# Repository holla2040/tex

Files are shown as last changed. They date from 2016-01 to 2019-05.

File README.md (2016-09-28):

# tex
    RaspberryPi super controller board for multiple uses: for example museum static airplanes, solar tracker and off-grid water turbine automation.  

### features
<pre>
Overview
    Sensors
        8 analog inputs multiplexed to 12bit ADC at 3KSPS
            Used for temperature, light, voltage, current,
            pressure, flow, AC line sync, etc
        1 power supply current sense ADC

    User Interface
        2 board-mounted user input switches
        3 board-mounted indicator LEDS: R,G,B
        1 128x64 White OLED Display Module
        All connectors are plug-type for easy board replacement
        
    Control
        16 PWM-driven voltage outputs at 7A max with board indicator
        4 dry-contact 10A relays with COM/NC/NO connector
        2 120VAC/8A solid-state relays
        2 DC Motor H-bridge drivers with current sense
            * uses 4 of 16 outputs from above
            Motor direction indicator
        2 opto-coupled inputs for DC motor motion encoders
        2 stepper motor driver signalling outputs, EN/DIR/PULSE
        10 uncommitted digital +5 I/O signals
        
    Peripherals
        Board tempurature sensor
        Battery backed real-time clock 

    Power Supply
        12-26VDC operation, PWM outputs switch this voltage
        +5V DC/DC converter
        Reverse battery protection
        ATF automobile fuse
        
    Communication
        WiFi/Bluetooth 4.0/Ethernet supplied on Raspberry Pi 3
        RS-485 2/4 wire with termination resistor
        External I2C/Power/Ground connector
</pre>
<hr>
<pre>
Detailed
    DC motor 1 h-bridge            discrete fets
    DC motor 1 encoder             cpu interrupt opto-coupled
    DC motor 1 current detect      gain
    DC motor 2 h bridge            discrete fets
    DC motor 2 encoder             cpu interrupt opto-coupled
    DC motor 2 current detect      gain
    AC SSR 1                       i/o slow, unfused
    AC SSR 2                       i/o slow, unfused
    Temperature sensor 1           multiplexed, 10k pullup
    Temperature sensor 2           multiplexed, 10k pullup
    Temperature sensor 3           multiplexed, 10k pullup
    Temperature sensor 4           multiplexed, 10k pullup
    Pyranometer                    analog input with gain
    LED Driver 0                   pwm
    LED Driver 1                   pwm
    LED Driver 2                   pwm
    LED Driver 3                   pwm
    LED Driver 4                   pwm
    LED Driver 5                   pwm
    LED Driver 6                   pwm
    LED Driver 7                   pwm
    LED Driver 8                   pwm
    LED Driver 9                   pwm
    LED Driver 10                  pwm
    LED Driver 11                  pwm
    LED Driver 12                  pwm, push-pull coupled with 13
    LED Driver 13                  pwm, push-pull coupled with 12
    LED Driver 14                  pwm, push-pull coupled with 15
    LED Driver 15                  pwm, push-pull coupled with 14
    Relay 0                        i/o slow, NO/NC contacts
    Relay 1                        i/o slow, NO/NC contacts
    Relay 2                        i/o slow, NO/NC contacts
    Relay 3                        i/o slow, NO/NC contacts
    E-stop input                   cpu interrupt
    Water Pressure                 0-5VDC input
    Water Flow Rate                0-5VDC input with scaler
    External AC voltage detect     0-5VDC input with scaler, half-wave
    External AC current sensor     0-5VDC input with scaler, half-wave
    External AC frequency sensor   use adc from AC V or I sensor
    External 5VDC I/O 0            I/O slow, change interrupt exists
    External 5VDC I/O 1            I/O slow, change interrupt exists
    External 5VDC I/O 2            I/O slow, change interrupt exists
    External 5VDC I/O 3            I/O slow, change interrupt exists
    External 5VDC I/O 4            I/O slow, change interrupt exists
    External 5VDC I/O 5            I/O slow, change interrupt exists
    External 5VDC I/O 6            I/O slow, change interrupt exists
    External 5VDC I/O 7            I/O slow, change interrupt exists
    External 5VDC I/O 8            I/O slow, change interrupt exists
    External 5VDC I/O 9            I/O slow, change interrupt exists
    Stepper control A              enable, direction, step outputs
    Stepper control B              enable, direction, step outputs
    Power supply current monitor   high-side current monitor
    Display                        OLED 0.96 mount intended
    Reverse Battery Protection     FET biased forward bias protection 
</pre>

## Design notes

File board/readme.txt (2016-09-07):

This information, board files, assembly instructions and bill of
materials are company confidental.
Not for distribution.

board
    tex

version
    v0.1

date
    160906

svn revision
    n/a

fudicials at
    6mm,6mm
    194mm,94mm

2 layer description
    2 layer board
        crc component cream
        plc component side silkscreen
        stc component side solder stop mask
        cmp component side copper
        sol solder side copper
        sts solder side solder stop mask
        pls solder side silkscreen
        crs solder cream

        drd drill data
        dri drill info
        gpi gerber info

2 layer stack up sequence
    top     x.cmp
    bottom  x.sol

contact info
    Craig Hollabaugh
    970 690 4911
    craig@hollabaugh.com

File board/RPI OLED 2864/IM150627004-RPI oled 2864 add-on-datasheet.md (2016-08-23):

# Raspberry PI OLED 2864 Add-on V2.0 #

## Introduction ##

There are seldom OLED add-ons customized for Raspberry Pi in the open source hardware market. In a lot of projects, we only need to display little information such as the state of system or IP. What’s more, when we have a high requirement for its portability, it’s unsuitable to connect a big screen to Raspberry Pi via HDMI interface. Thus, a tiny OLED add-on can satisfy this demand.

OLED add-on with built-in 0.96" 128*64 OLED and SSD1306 control chip is customized for Raspberry Pi. Every single pixel in OLED can be lighted up or off by this SSD1306 control chip.

We not only offer an easily-plugged add-on for Raspberry Pi, but also provide an SDK that help you transplant Arduino’s driver into Raspberry Pi. After installing the SDK, you can drive this add-on as easily as you do on Arduino.

## Feature ##

- Customized for Raspberry Pi, plug and play without wiring

- 0.96" OLED with 128*64 pixels

- Stackable

- Coming with 2.54 interface for Electronic bricks

## Specification ##

<table>
<tr>
  <th>PCB size</th>
  <td>65mm X 43mm X 1.6mm</td>
</tr>
<tr>
  <th>Operation Level</th>
  <td>Digital 3.3V DC</td>
</tr>
</table>

## Hardware ##

请看IM150627004-RPI oled 2864 add-on-dimension.pdf

## Pinmap ##

<table>
<tr>
  <th>Raspberry PI Pin N.O.</th>
  <th>Pin name</th>
  <th>Description</th>
</tr>
<tr>
  <td>1</td>
  <td>3.3V</td>
  <td></td>
</tr>
<tr>
  <td>2</td>
  <td>5V</td>
  <td></td>
</tr>
<tr>
  <td>3</td>
  <td>GPIO02</td>
  <td>OLED_SDA</td>
</tr>
<tr>
  <td>4</td>
  <td>5V</td>
  <td></td>
</tr>
<tr>
  <td>5</td>
  <td>GPIO03</td>
  <td>OLED_SCL</td>
</tr>
<tr>
  <td>6</td>
  <td>GND</td>
  <td></td>
</tr>
<tr>
  <td>7</td>
  <td>GPIO04</td>
  <td>OLED_RST</td>
</tr>
<tr>
  <td>8</td>
  <td>GPIO14</td>
  <td>TXD</td>
</tr>
<tr>
  <td>9</td>
  <td>GND</td>
  <td></td>
</tr>
<tr>
  <td>10</td>
  <td>GPIO15</td>
  <td>RXD</td>
</tr>
<tr>
  <td>11</td>
  <td>GPIO17</td>
  <td></td>
</tr>
<tr>
  <td>12</td>
  <td>GPIO18</td>
  <td></td>
</tr>
<tr>
  <td>13</td>
  <td>GPIO27</td>
  <td></td>
</tr>
<tr>
  <td>14</td>
  <td>GND</td>
  <td></td>
</tr>
<tr>
  <td>15</td>
  <td>GPIO22</td>
  <td></td>
</tr>
<tr>
  <td>16</td>
  <td>GPIO23</td>
  <td></td>
</tr>
<tr>
  <td>17</td>
  <td>3.3V</td>
  <td></td>
</tr>
<tr>
  <td>18</td>
  <td>GPIO24</td>
  <td></td>
</tr>
<tr>
  <td>19</td>
  <td>GPIO10</td>
  <td>SPI_MOSI</td>
</tr>
<tr>
  <td>20</td>
  <td>GND</td>
  <td></td>
</tr>
<tr>
  <td>21</td>
  <td>GPIO09</td>
  <td>SPI_MISO</td>
</tr>
<tr>
  <td>22</td>
  <td>GPIO25</td>
  <td></td>
</tr>
<tr>
  <td>23</td>
  <td>GPIO11</td>
  <td>SPI_SCK</td>
</tr>
<tr>
  <td>24</td>
  <td>GPIO08</td>
  <td>SPI_CE0</td>
</tr>
<tr>
  <td>25</td>
  <td>GND</td>
  <td></td>
</tr>
<tr>
  <td>26</td>
  <td>GPIO07</td>
  <td>SPI_CE1</td>
</tr>
<tr>
  <td>27</td>
  <td>ID_SD</td>
  <td></td>
</tr>
<tr>
  <td>28</td>
  <td>ID_SC</td>
  <td></td>
</tr>
<tr>
  <td>29</td>
  <td>GPIO05</td>
  <td></td>
</tr>
<tr>
  <td>30</td>
  <td>GND</td>
  <td></td>
</tr>
<tr>
  <td>31</td>
  <td>GPIO06</td>
  <td></td>
</tr>
<tr>
  <td>32</td>
  <td>GPIO12</td>
  <td></td>
</tr>
<tr>
  <td>33</td>
  <td>GPIO13</td>
  <td></td>
</tr>
<tr>
  <td>34</td>
  <td>GND</td>
  <td></td>
</tr>
<tr>
  <td>35</td>
  <td>GPIO19</td>
  <td></td>
</tr>
<tr>
  <td>36</td>
  <td>GPIO16</td>
  <td></td>
</tr>
<tr>
  <td>37</td>
  <td>GPIO26</td>
  <td></td>
</tr>
<tr>
  <td>38</td>
  <td>GPIO20</td>
  <td></td>
</tr>
<tr>
  <td>39</td>
  <td>GND</td>
  <td></td>
</tr>
<tr>
  <td>40</td>
  <td>GPIO21</td>
  <td></td>
</tr>
</table>

## Download ##

schematic: 请看IM150627004-RPI oled 2864 add-on-schematic.pdf

## Useful Link ##

https://github.com/itead/SDK

https://github.com/itead/SDK/tree/master/libraries/itead_SSD1306

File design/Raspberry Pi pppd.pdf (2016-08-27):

let's make | Explore (/tag/typeid/) (http://www.instructables.com/tag/type-id/) | Publish (/about/create.jsp) (http://www.instructables.com/about/create.jsp)
| Classes NEW! (/classes/) (http://www.instructables.com/classes/)
Featured: (http://www.instructables.com/) | (/tag/typeid/categorycraft/channelleather/) (http://www.instructables.com/tag/type-id/category-craft/channel-leather/) Leather (/tag/typeid/categorycraft/channelleather/) (http://www.instructables.com/tag/type-id/category-craft/channel-leather/)
(/tag/typeid/categoryoutside/channelcamping/) (http://www.instructables.com/tag/type-id/category-outside/channel-camping/) Camping (/tag/typeid/categoryoutside/channelcamping/) (http://www.instructables.com/tag/type-id/category-outside/channel-camping/) | (/id/intel/) (http://www.instructables.com/id/intel/) Intel IoT (/id/intel/) (http://www.instructables.com/id/intel/)

(/id/Fusion/) (http://www.instructables.com/id/Fusion/) Fusion 360 (/id/Fusion/) (http://www.instructables.com/id/Fusion/)

In this tutorial I will show you how to connect your Raspberry Pi to the Internet just by using its serial line (http://elinux.org/RPi_Serial_Connection) which is accessible on GPIO (http://pi.gadgetoid.com/pinout/uart). This can be very helpful if there is no other means of connection available like ethernet or wifi dongle. The UART serial port is not directly suitable for TCP/IP traffic so we are going to use a PPP protocol that will encapsulate the serial link and give us an IP interface. Please note that the UART is designed to work in kilobits speed range (115.2kbit by default), that's sufficient for ssh and small files transfers, but it will take ages to transfer large files.

The operating principle is very simple, but it may be tricky to setup things properly, especially if your communication is limited to UART only. What you'll need:
Raspberry PI (any model) with Raspbian
USB <> UART convertor + cable with 3.3v logic levels
A linux computer that will act as a second serial link endpoint and a network gateway
Optionally a monitor / keyboard / ethernet / wifi that you can plug to your Raspberry
This method is particularly suitable for the model A as it lacks an ethernet port, but it will work with any Raspberry model. I have the model B rev1.0 :) The convertor can be of any type, I'm using a cheap convertor with a CP2102 chip. As a second endpoint, I'm using my Ubuntu laptop. You don't need anything

(/file/F5BWXWHI4C2R3YB/)

About This Instructable

8 22,992 views

- 32 favorites

Posted:
Dec 31, 2014
License:

(/member/ludeks/)

lude (http://www.instructables.com/member/ludeks/)ks
(/me (http://www.instructables.com/member/ludeks/)mber/ludeks/)

Follow (http://www.instructables.com/member/ludeks/) 1

More by ludeks:

(/id/Connectthe-

Raspberry-Pitonetworkusing-UART/) (http://www.instructables.com/id/Connect-the-Raspberry-Pi-to-network-using-UART/)

raspberry pi (/howto/raspberry%20pi/) (http://www.instructables.com/howto/raspberry%20pi/)

uart (/howto/uart/) (http://www.instructables.com/howto/uart/) serial (/howto/serial/) (http://www.instructables.com/howto/serial/)

ppp (/howto/ppp/) (http://www.instructables.com/howto/ppp/)

Tags:

Add instructable to:

; Group

Related

JT (http://www.instructables.com/id/JTAGulating-the-Raspberry-Pi-2/)AGulating the Raspberry
Pi (http://www.instructables.com/id/JTAGulating-the-Raspberry-Pi-2/) 2 (/id/JTAGulatingthe-Ra (http://www.instructables.com/id/JTAGulating-the-Raspberry-Pi-2/)spberry-Pi-2/)
by (http://www.instructables.com/id/JTAGulating-the-Raspberry-Pi-2/) Tymkrs (/member/Tymkrs/) (http://www.instructables.com/member/Tymkrs/)

RA (http://www.instructables.com/id/RASPBERRY-PI-3-and-RASPBIAN-JESSIE-GSM-3G-SERIAL-H/)SPBERRY PI 3 (and
RA (http://www.instructables.com/id/RASPBERRY-PI-3-and-RASPBIAN-JESSIE-GSM-3G-SERIAL-H/)SPBIAN JESSIE) GSM 3G
SE (http://www.instructables.com/id/RASPBERRY-PI-3-and-RASPBIAN-JESSIE-GSM-3G-SERIAL-H/)RIAL HOW TO
(/id (http://www.instructables.com/id/RASPBERRY-PI-3-and-RASPBIAN-JESSIE-GSM-3G-SERIAL-H/)/RASPBERRY-PI-3-and- (http://www.instructables.com/id/RASPBERRY-PI-3-and-RASPBIAN-JESSIE-GSM-3G-SERIAL-H/)RASPBIAN-JESSIE-GSM-3G-
Hello world to Raspberry Pi through Seeeduino (Uart
port) (/id/Helloworldto-Raspberry-Pithrough- (http://www.instructables.com/id/Hello-world-to-Raspberry-Pi-through-Seeeduino-Uart/)Seeeduino-Uart/)
RFID Based Attendance
System Using Raspberry Pi
(/id/RFID-Based-Attendance (http://www.instructables.com/id/RFID-Based-Attendance-System-Using-Raspberry-Pi/)

(/) (http://www.instructables.com/)

Download

- Collection | I Made it! | Favorite

Connec (http://www.instructables.com/id/Fusion/)t the Raspberry (http://www.instructables.com/id/Fusion/) Pi to network using UART by ludeks (/member/ludeks/) (http://www.instructables.com/member/ludeks/)

7 Steps | .
- | Share |

h (/id/Connectthe-Raspberry-Pitonetworkusing-UART/) (http://www.instructables.com/id/Connect-the-Raspberry-Pi-to-network-using-UART/) sh (http://www.instructables.com/)are what you make (http://www.instructables.com/tag/type-id/category-craft/channel-leather/)

You (/you/) (http://www.instructables.com/you/)

else to plug in to your Raspberry if you setup things correctly, but having a monitor + keyboard and ethernet connection will make the setup easier and can greatly help in case something doesn't work as expected. I needed to connect my Raspberry to the network and I had only a monitor, so it was a lot of trial & error for me to get it working.

### Step 1: Identify USB UART convertor RX / TX lines

You'll need to be sure which pins on the converter are the RX / TX serial lines. Don't rely on markings on the convertor PCB as they may not be correct! You can skip this step if you know which lines are TX and RX.

If you are not sure which line is TX, you can attach a resistor and LED in series to the suspected pin, the LED should blink when you write something to the UART.

Assuming the /dev/ttyUSB0 is the convertor:

# This will make a LED attached to the TX blink once stty -F /dev/ttyUSB0 9600 raw

dd if=/dev/zero of=/dev/ttyUSB0 bs=1000 count=1

Once you have identified the TX pin, you can connect it to the suspected RX pin on the converter to make an echo loop. You should be able to receive what you write to it.

screen /dev/ttyUSB0 115200

When you type characters to the screen session, the screen should echo them when TX-RX are connected.

### Step 2: Wire your computer to the Raspberry Pi

Raspberry Pi Dumb Terminal (/id/Raspberry-Pi-Dumb-Terminal/) (http://www.instructables.com/id/Raspberry-Pi-Dumb-Terminal/)
by Tymkrs (/member/Tymkrs/) (http://www.instructables.com/member/Tymkrs/)

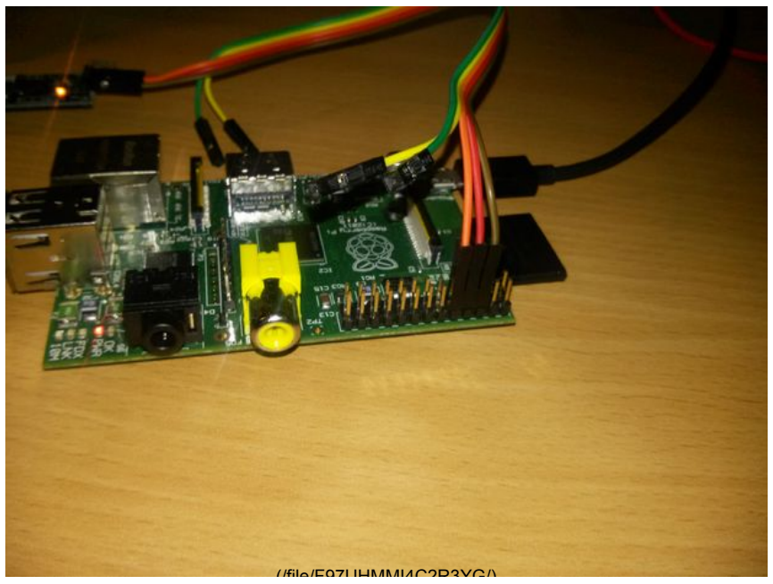
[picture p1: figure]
(/file/F97UHMMI4C2R3YG/)

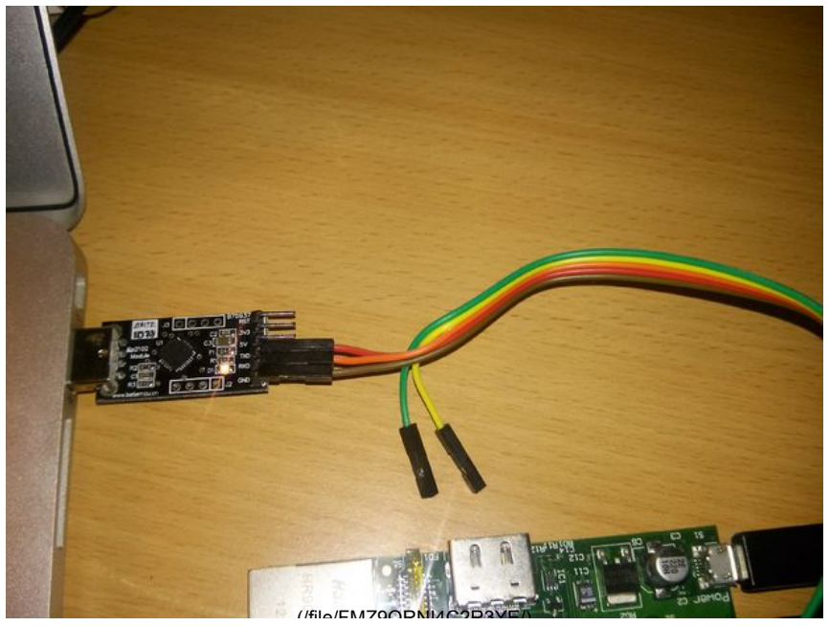
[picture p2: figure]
(/file/FMZ9QRNI4C2R3YE/)

Connect your USB <> UART convertor to the Raspberry Pi. You need to connect TX, RX and GND lines. TX stands for "transmitter" and RX stands for "receiver". When connecting two UART devices, you must connect them in a way that TX and RX form a crossover. That means that the output from a TX pin on one device goes to an RX input pin on the other device and vice versa. This is sometimes called a nullmodem.

UART Convertor | Raspberry PI GPIO
GND GND
TX output pin RXD pin 10 on GPIO header
RX input pin TXD pin 8 on GPIO header

Make sure that your convertor uses 3.3v logic levels output! The Raspberry uses 3.3v logic on its GPIO and higher voltage may damage the GPIO! If your convertor uses 5v logic levels you must use some logic level convertor.

### Step 3: Test the connection using a console

By default, the Raspbian uses the builtin UART for linux console access and kernel debugging. Now, we will take advantage of this to test our wiring. Later we will disable this feature and use the UART for networking exclusively.

The Raspi's UART is accessible via /dev/ttyAMA0 special device.

First, make sure that the serial console is enabled. In cmdline.txt (http://elinux.org/RPi_cmdline.txt), you should see something like:

dwc_otg.lpm_enable=0 console=ttyAMA0,115200 kgdboc=ttyAMA0,115200 consol e=tty1 root=/dev/mmcblk0p2 rootfstype=ext4 elevator=deadline rootwait

The most important part is console=ttyAMA0,115200 this will tell the kernel to assume the UART as a system console.

Edit the file manually or use a raspiconfig (Advanced options) to enable the console on the serial port.

Second, on your linux computer, type:

screen /dev/ttyUSB0 115200

This will connect to the Raspberry Pi console. You should see a login prompt and be able to login. If you don't see anything, try pressing Enter. Also you should see kernel messages while the Raspi boots.

You can use the the serial console to connect to the Raspberry Pi if you don't have a monitor and a keyboard. Just make sure that the console is enabled in the cmdline.txt

Once you've checked that the serial connection works, you can proceed to the next step.

### Step 4: Install necessary tools

You will need the 'pppd' tool to manage the connection. It is a part of the 'ppp' package.

Install the ppp package both to your linux host and the Raspberry Pi:

sudo aptget install ppp

If you don't have an access to the Internet already from your Raspberry Pi (a chickenegg problem) you can manually download the .deb packages, place them on the sd card or a flash drive and manually install them. Just make sure you download and install all the dependencies.

sudo dpkg i xyz.deb

### Step 5: Take over the Raspberry Pi's UART

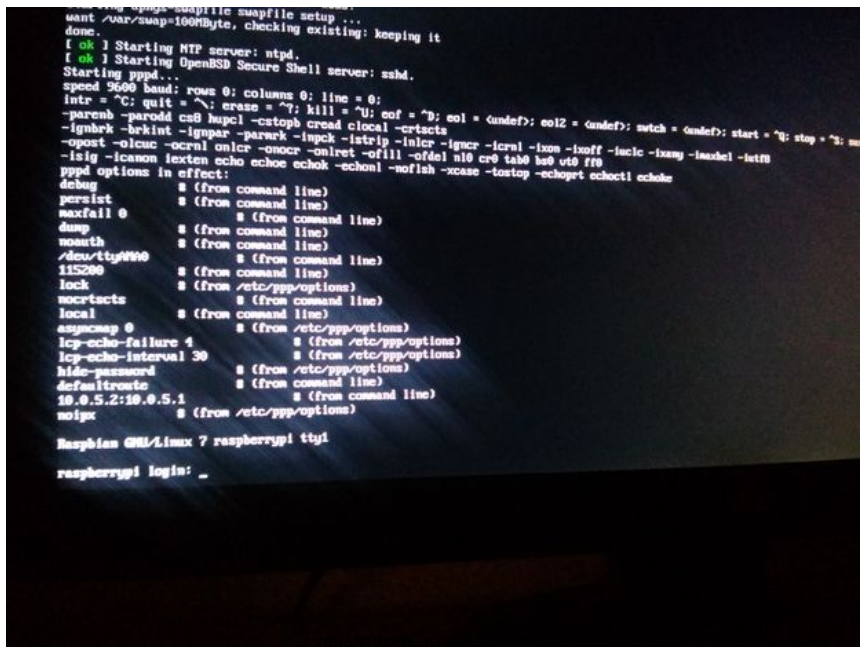
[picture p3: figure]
(/file/FZP3LJVI4C2R3YD/)

Now, when the serial link reliably works. We can disable the console feature and use the UART exclusively for networking.

First, remove all ttyAMA0 references from cmdline.txt, refer to the previous step if you don't know how:

dwc_otg.lpm_enable=0 console=tty1 root=/dev/mmcblk0p2 rootfstype=ext4 elev ator=deadline rootwait

On next reboot, you'll be able to use ttyAMA0 for whatever you like.

In our case we will configure the UART for some reasonable behavior and start PPP Daemon to establish a connection over the wire.

These commands will basically do what we need:

stty -F /dev/ttyAMA0 raw
pppd /dev/ttyAMA0 115200 10.0.5.2:10.0.5.1 noauth local debug dump default route nocrtscts

The IP addresses 10.0.5.2 and 10.0.5.1 denote local:remote addresses being used for the connection. You can chose any IP addresses, just make sure the network range is different from what you are already using. In our case the 10.0.5.2 will be the address of our Pi, the 10.0.5.1 will be address of our linux host.

As I don't have any access to the RaspberryPi apart from the serial port, I tweaked the pppd parameters a little bit and added them to the /etc/rc.local (http://www.raspberrypi.org/documentation/linux/usage/rclocal.md) script so they execute every time the Raspberry boots and the pppd keeps running all the time so I can connect & disconnect the Raspberry at will.

My rc.local:

echo "Starting pppd..."
stty -F /dev/ttyAMA0 raw
stty -F /dev/ttyAMA0 a
pppd /dev/ttyAMA0 115200 10.0.5.2:10.0.5.1 noauth local debug dump default route nocrtscts persist maxfail 0 holdoff 1

The 'persist maxfail 0 holdoff 1' parameters will make the pppd attempt connect forever.

When you plug a monitor to your Raspberry, you should see an output of the startup script on the screen.

### Step 6: Run pppd on host

Start the ppp daemon on your computer:

sudo stty -F /dev/ttyUSB0 raw
sudo pppd /dev/ttyUSB0 115200 10.0.5.1:10.0.5.2 proxyarp local noauth debu g nodetach dump nocrtscts passive persist maxfail 0 holdoff 1

When pppd is running on both devices, they should handshake and establish a link. The output should like this:

using channel 10
Using interface ppp0
Connect: ppp0 <> /dev/ttyUSB0
sent [LCP ConfReq id=0x5 <asyncmap 0x0> <magic 0xb4bad9a9> <pcomp> <accom p>]
rcvd [LCP ConfReq id=0x2 <asyncmap 0x0> <magic 0x263f80e1> <pcomp> <accom p>]
sent [LCP ConfAck id=0x2 <asyncmap 0x0> <magic 0x263f80e1> <pcomp> <accom p>]
rcvd [LCP ConfAck id=0x5 <asyncmap 0x0> <magic 0xb4bad9a9> <pcomp> <accom p>]
sent [LCP EchoReq id=0x0 magic=0xb4bad9a9]
sent [CCP ConfReq id=0x4 <deflate 15> <deflate(old#) 15> <bsd v1 15>] sent [IPCP ConfReq id=0x4 <compress VJ 0f 01> <addr 10.0.5.1>]
rcvd [LCP EchoReq id=0x0 magic=0x263f80e1]
sent [LCP EchoRep id=0x0 magic=0xb4bad9a9]
rcvd [LCP EchoRep id=0x0 magic=0x263f80e1]
rcvd [CCP ConfReq id=0x2 <deflate 15> <deflate(old#) 15> <bsd v1 15>] sent [CCP ConfAck id=0x2 <deflate 15> <deflate(old#) 15> <bsd v1 15>] rcvd [IPCP ConfReq id=0x2 <compress VJ 0f 01> <addr 10.0.5.2>]
sent [IPCP ConfAck id=0x2 <compress VJ 0f 01> <addr 10.0.5.2>]
rcvd [CCP ConfAck id=0x4 <deflate 15> <deflate(old#) 15> <bsd v1 15>] Deflate (15) compression enabled
rcvd [IPCP ConfAck id=0x4 <compress VJ 0f 01> <addr 10.0.5.1>]
Cannot determine ethernet address for proxy ARP
local IP address 10.0.5.1
Now, from you linux host, you should be able to ping or ssh the RaspberryPi

ping 10.0.5.2

If the ping works, you can proceed to the next step.

### Step 7: Setup routing and NAT

Once we've established an IP link between our computer and the Raspberry Pi, we can configure the computer to route traffic from the Raspi to the Internet.

First, enable the traffic forwarding (http://www.ducea.com/2006/08/01/howtoenableipforwardinginlinux/): (http://www.ducea.com/2006/08/01/how-to-enable-ip-forwarding-in-linux/)

sudo sysctl w net.ipv4.ip_forward=1

Next, enable the NAT masquerade to translate Raspi's internal address to the computer's address. Assuming the 'eth0' is an interface on your computer that you use to connect to the outside world:

sudo iptables t nat -A POSTROUTING o eth0 j MASQUERADE

Now, you should be able to ssh to the Raspberry and ping some internet server :)

ssh pi@10.0.5.2

Finished!

We have a be nice comment policy.
Please be positive and constructive. | w I Made it! | Add Images | Post Comment

Feature Comment [delete]

an hour ago | Reply
X | 9 months ago | Reply

Reply
9 months ago

8

X | 2 years ago | Reply |

8

holla2040 (/member/holla2040) (http://www.instructables.com/member/holla2040)
Thanks for putting this together. This is exactly what I need for an offgrid hydro automation project.

MaykeS1 (/member/MaykeS1) (http://www.instructables.com/member/MaykeS1)
There's no log in prompt after the connection is established. Any ideas on that?

ludeks (/member/ludeks) (http://www.instructables.com/member/ludeks) (author) . MaykeS1 (/member/MaykeS1) (http://www.instructables.com/member/MaykeS1)

Hi, you either use the UART for a console OR ppp network
link. To be able to log in over UART, make sure the console is enabled ("console=ttyAMA0,115200" in cmdline.txt). If you use UART for networking, you can then log in over ssh.

seamster (/member/seamster) (http://www.instructables.com/member/seamster)
Nicely done. Thanks for sharing this!

Flag

Flag

Flag

Flag

## FEATURED CHANNELS

Woodworking
(/tag/typeid/categoryworkshop/channelwoodworking/) (http://www.instructables.com/tag/type-id/category-workshop/channel-woodworking/)

Paper
(/tag/typeid/categorycraft/channelpaper/) (http://www.instructables.com/tag/type-id/category-craft/channel-paper/)

Kitchen Hacks
(/tag/typeid/keywordkitchen%20hacks/?
sort=FAVORITES) (http://www.instructables.com/tag/type-id/keyword-kitchen%20hacks/?sort=FAVORITES)

Puzzles
(/tag/typeid/categoryplay/channelpuzzles/) (http://www.instructables.com/tag/type-id/category-play/channel-puzzles/)

Space
(/tag/typeid/keywordastronomy/?
sort=FAVORITES) (http://www.instructables.com/tag/type-id/keyword-astronomy/?sort=FAVORITES)

Ice Cream
(/tag/typeid/keywordice%20cream/? (http://www.instructables.com/tag/type-id/keyword-ice%20cream/?sort=FAVORITES)
s (http://www.instructables.com/tag/type-id/keyword-astronomy/?sort=FAVORITES)ort=FAVORITES) (http://www.instructables.com/tag/type-id/keyword-ice%20cream/?sort=FAVORITES)

Homesteading
(/tag/typeid/categoryhome/channelhomesteading/) (http://www.instructables.com/tag/type-id/category-home/channel-homesteading/)

3D Printing
(/tag/typeid/categorytechnology/channel-3D-Printing/) (http://www.instructables.com/tag/type-id/category-technology/channel-3D-Printing/)

Sewing
(/tag/typeid/category- (http://www.instructables.com/tag/type-id/category-craft/channel-sewing/)c (http://www.instructables.com/tag/type-id/category-technology/channel-3D-Printing/)raft/channel-
sewing/) (http://www.instructables.com/tag/type-id/category-craft/channel-sewing/) Newsletter

Join 2 million + to receive instant
DIY inspiration in your inbox.
enter email | I'm in!

About Us

Who We Are (/about/) (http://www.instructables.com/about/)
Advertise (/advertise/) (http://www.instructables.com/advertise/)
Contact (/about/contact.jsp) (http://www.instructables.com/about/contact.jsp)
Jobs (/community/Positionsavailableat-Instructables/) (http://www.instructables.com/community/Positions-available-at-Instructables/) Help (/id/howtowriteagreatinstructable/) (http://www.instructables.com/id/how-to-write-a-great-instructable/)

Find Us

Facebook (http://www.facebook.com/instructables) Youtube (http://www.youtube.com/user/instructablestv) Twitter (http://www.twitter.com/instructables) Pinterest (http://www.pinterest.com/instructables) Google+ (https://plus.google.com/+instructables)
Resources

For Teachers (/teachers/) (http://www.instructables.com/teachers/)
Artists in Residence (/air) (http://www.instructables.com/air)
Gift Premium Account (/account/give?sourcea=footer) (http://www.instructables.com/account/give?sourcea=footer) Forums (/community/) (http://www.instructables.com/community/)
Answers (/tag/typequestion/?sort=RECENT) (http://www.instructables.com/tag/type-question/?sort=RECENT) Sitemap (/sitemap/) (http://www.instructables.com/sitemap/)

Mobile

Download our apps!

Android » (https://play.google.com/store/apps/details?id=com.adsk.instructables)
iOS » (https://itunes.apple.com/app/instructables/id586765571)
Windows » (http://apps.microsoft.com/windows/enus/app/7afc8194-c771-441a-9590-54250d6a8300) (http://apps.microsoft.com/windows/en-us/app/7afc8194-c771-441a-9590-54250d6a8300)

Terms of Service (http://usa.autodesk.com/adsk/servlet/item?siteID=123112&id=21959721) |
Privacy Statement (http://usa.autodesk.com/adsk/servlet/item?siteID=123112&id=21292079) |
Legal Notices & Trademarks (http://usa.autodesk.com/legalnoticestrademarks/) (http://usa.autodesk.com/legal-notices-trademarks/) | Mobile Site (http://www.instructables.com)
(http://usa.autodesk.com/adsk/servlet/pc/index?id=20781545&siteID=123112) © 2016 Autodesk, Inc.

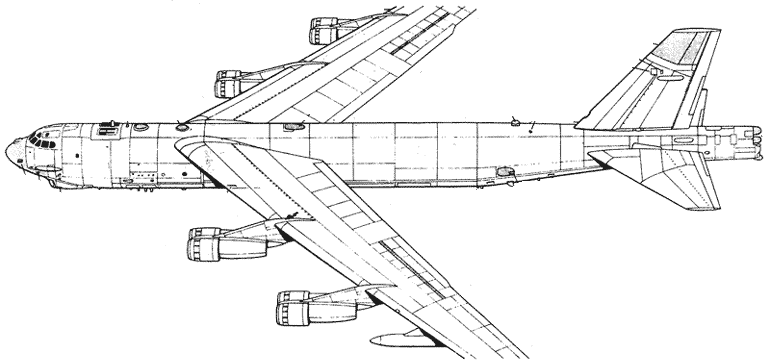
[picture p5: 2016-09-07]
board/b52_ant.bmp

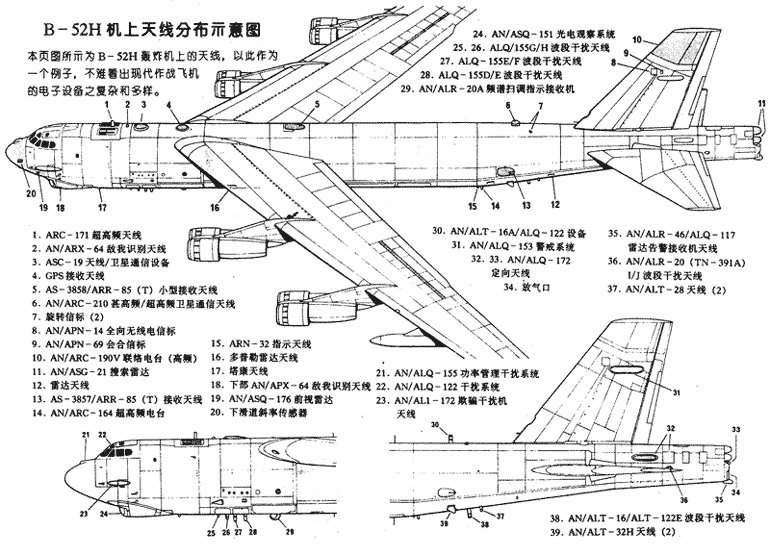
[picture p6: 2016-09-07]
board/b52_ant.gif

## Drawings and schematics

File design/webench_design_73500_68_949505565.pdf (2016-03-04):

## WEBENCH ® Design Report

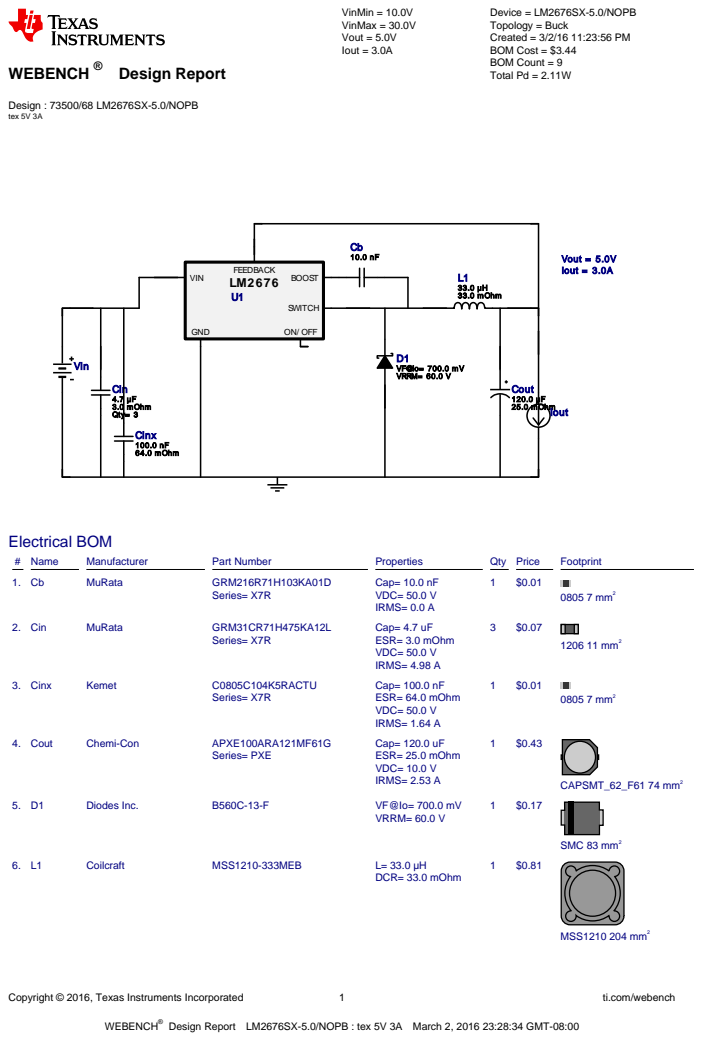
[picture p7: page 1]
Copyright © 2016, Texas Instruments Incorporated; ti.com/webench; WEBENCH®; Design : 73500/68 LM2676SX-5.0/NOPB tex 5V 3A; VinMin = 10.0V VinMax = 30.0V Vout = 5.0V Iout = 3.0A; Device = LM2676SX-5.0/NOPB Topology = Buck Created = 3/2/16 11:23:56 PM BOM Cost = $3.44 BOM Count = 9 Total Pd = 2.11W; Cin; mOhm; Qty= 3; Cinx 100.0 nF 64.0 mOhm; Cout 120.0 µF 25.0 mOhm; D1 VF@Io= 700.0 mV VRRM= 60.0 V; L1 33.0 µH 33.0 mOhm; LM2676 VIN; FEEDBACK; BOOST; SWITCH; GND; ON/ OFF; Vout = 5.0V Iout = 3.0A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

Design Report LM2676SX-5.0/NOPB : tex 5V 3A March 2, 2016 23:28:34 GMT-08:00

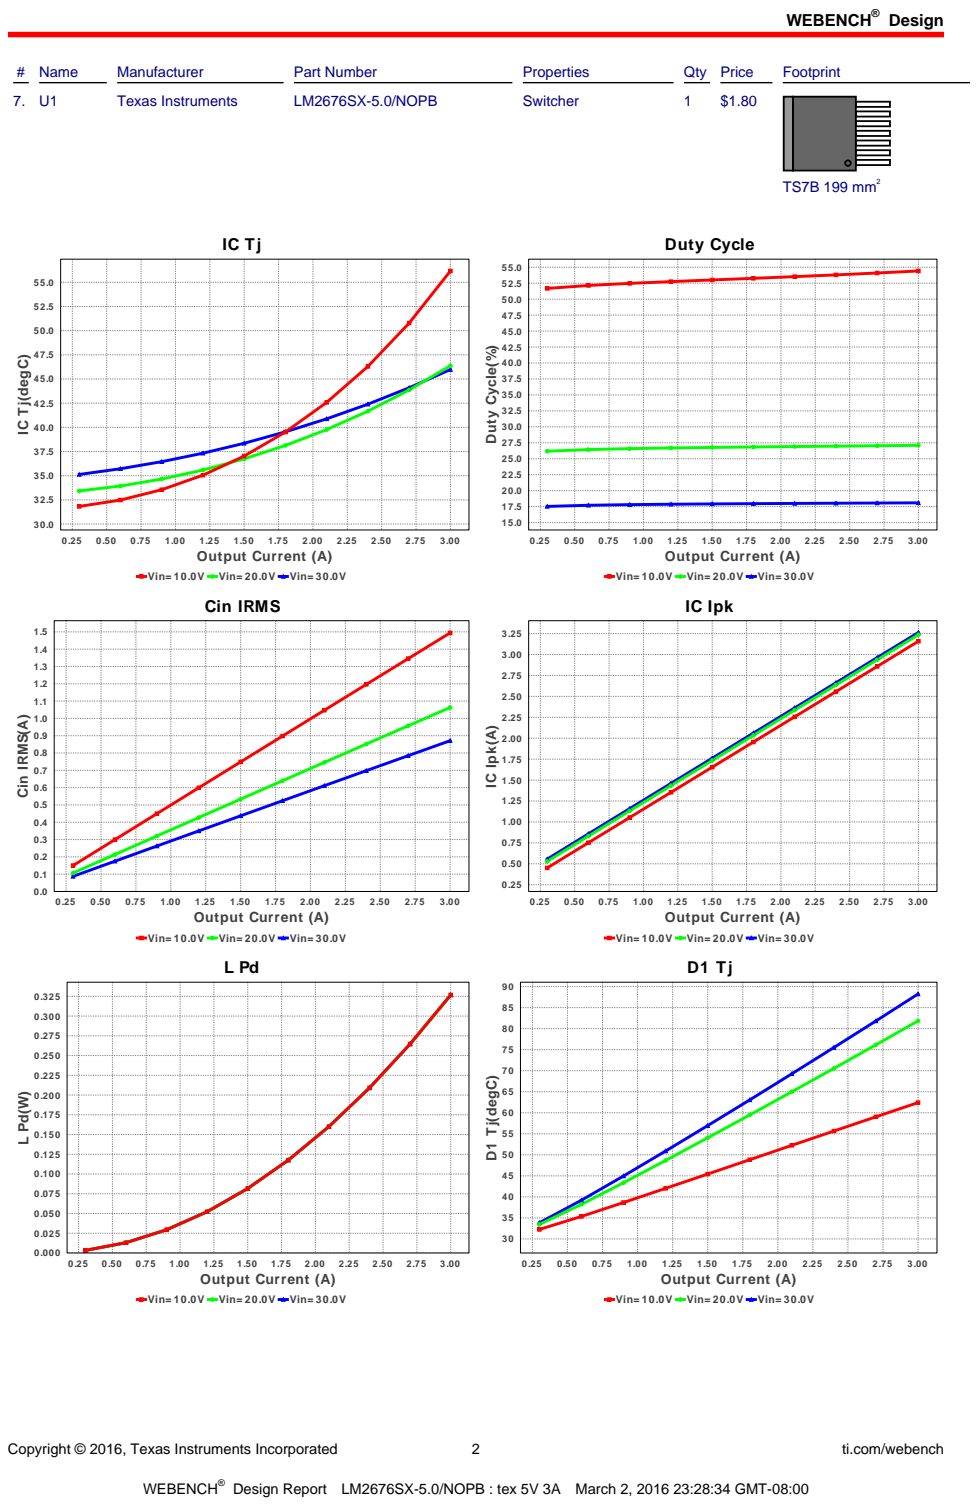
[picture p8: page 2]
Design; Copyright © 2016, Texas Instruments Incorporated; ti.com/webench; # Name; Manufacturer; Part Number; Properties; Qty Price; Footprint; Texas Instruments; LM2676SX-5.0/NOPB; Switcher; TS7B 199 mm²; 3.00 Output Current (A); Duty Cycle; Duty Cycle(%); Cin IRMS(A); IC Ipk; IC Ipk(A); D1 Tj(degC)

IC Tj(degC)

Vin= 10.0V Vin= 20.0V Vin= 30.0V
Cin IRMS

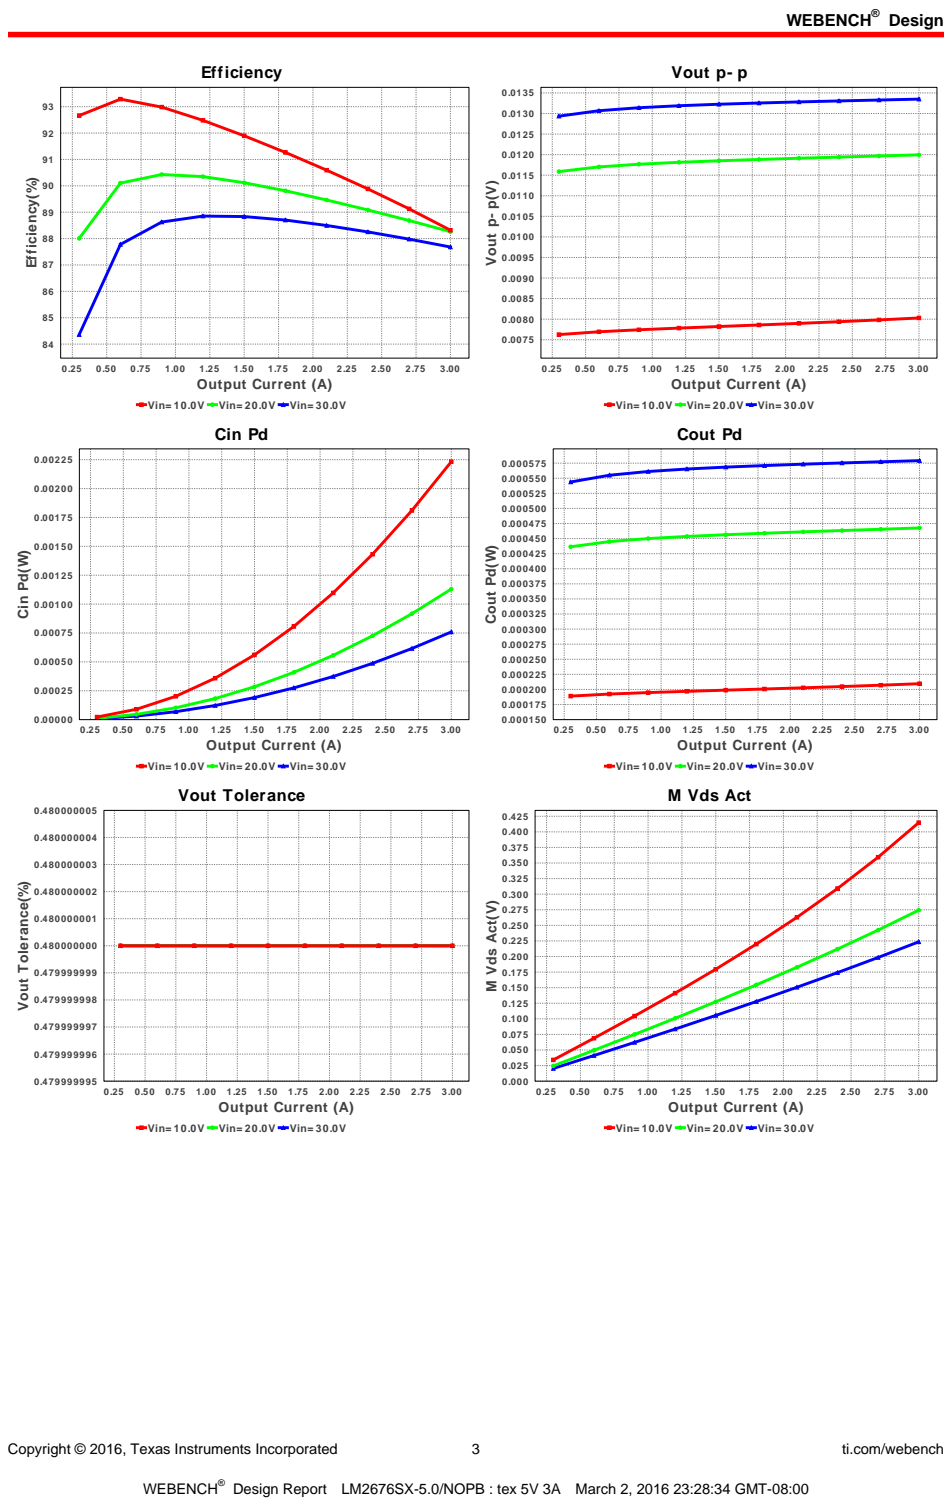
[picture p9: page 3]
Copyright © 2016, Texas Instruments Incorporated; ti.com/webench; Efficiency; 3.00 Output Current (A); Efficiency(%); Vout p- p; Vout p- p(V); Cin Pd; 0.25 0.50 0.75 1.00 1.25 1.50 1.75 2.00 2.25 2.50 2.75 3.00 Output Current (A); Cin Pd(W); Cout Pd; Cout Pd(W); Vout Tolerance(%); M Vds Act(V)

Vin= 10.0V Vin= 20.0V Vin= 30.0V

Vout Tolerance

M Vds Act

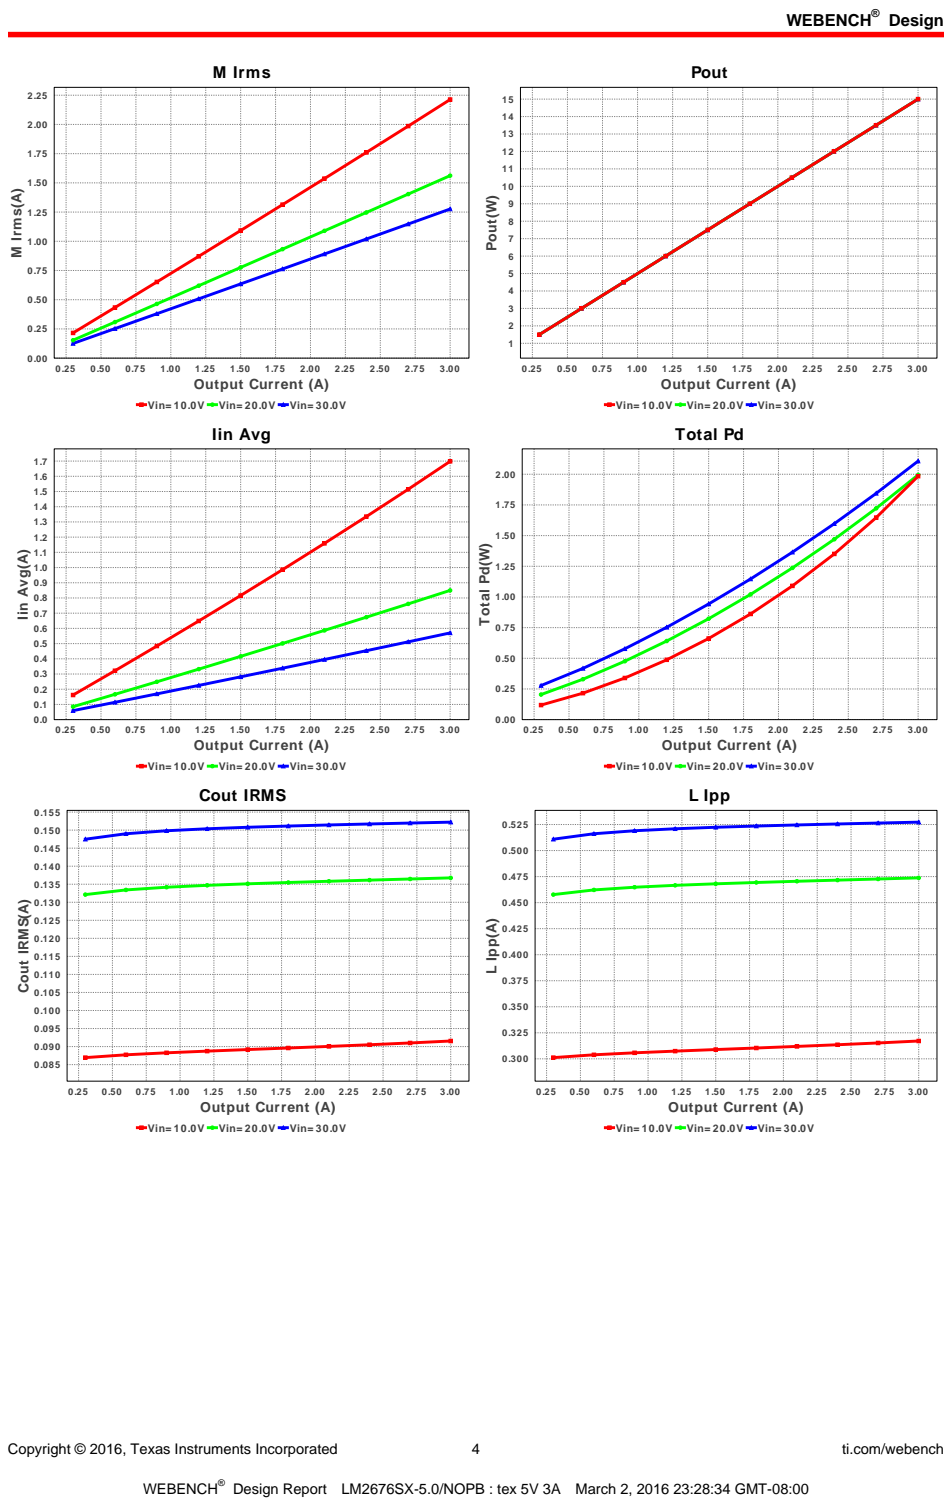
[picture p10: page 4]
Copyright © 2016, Texas Instruments Incorporated; ti.com/webench; M Irms; 3.00 Output Current (A); M Irms(A); Pout; Pout(W); Iin Avg; Iin Avg(A); Total Pd; Total Pd(W); Cout IRMS(A); L Ipp; L Ipp(A)

Vin= 10.0V Vin= 20.0V Vin= 30.0V

Cout IRMS

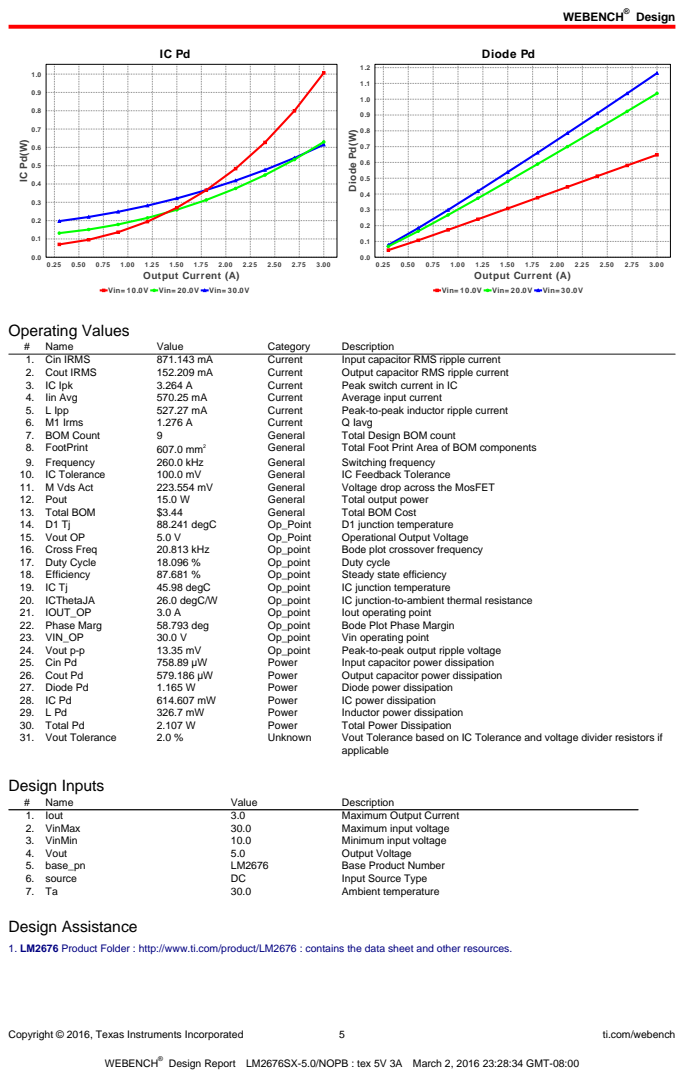
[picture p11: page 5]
Copyright © 2016, Texas Instruments Incorporated; ti.com/webench; 3.00 Output Current (A); Diode Pd; Diode Pd(W); Operating Values; Name; Value; Category; Description; 1. Cin IRMS; Current; Input capacitor RMS ripple current; 2. Cout IRMS; Output capacitor RMS ripple current; 3. IC Ipk; Peak switch current in IC; 4. Iin Avg; Average input current; 5. L Ipp; Peak-to-peak inductor ripple current; 6. M1 Irms; Q Iavg; 7. BOM Count; General; Total Design BOM count; 8. FootPrint; 607.0 mm²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

Vin= 10.0V Vin= 20.0V Vin= 30.0V

1. LM2676 Product Folder : http://www.ti.com/product/LM2676 : contains the data sheet and other resources.

Copyright © 2016, Texas Instruments Incorporated | 6 | ti.com/webench

Texas Instruments' WEBENCH simulation tools attempt to recreate the performance of a substantially equivalent physical implementation
of the design. Simulations are created using Texas Instruments' published specifications as well as the published specifications of other device manufacturers. While Texas Instruments does update this information periodically, this information may not be current at the time the simulation is built. Texas Instruments does not warrant the accuracy or completeness of the specifications or any information contained therein. Texas Instruments does not warrant that any designs or recommended parts will meet the specifications you entered, will be suitable for your application or fit for any particular purpose, or will operate as shown in the simulation in a physical implementation. Texas Instruments does not warrant that the designs are production worthy.
You should completely validate and test your design implementation to confirm the system functionality for your application prior to production.
Use of Texas Instruments' WEBENCH simulation tools is subject to Texas Instruments' Site Terms and Conditions of Use. (http://www.ti.com/corp/docs/legal/termsofuse.shtml) Prototype boards based on WEBENCH created designs are provided AS IS without warranty of any kind for evaluation and testing purposes and are subject to the terms of the Evaluation License Agreement. (http://www.ti.com/corp/docs/legal/termsofuse_estore.shtml)

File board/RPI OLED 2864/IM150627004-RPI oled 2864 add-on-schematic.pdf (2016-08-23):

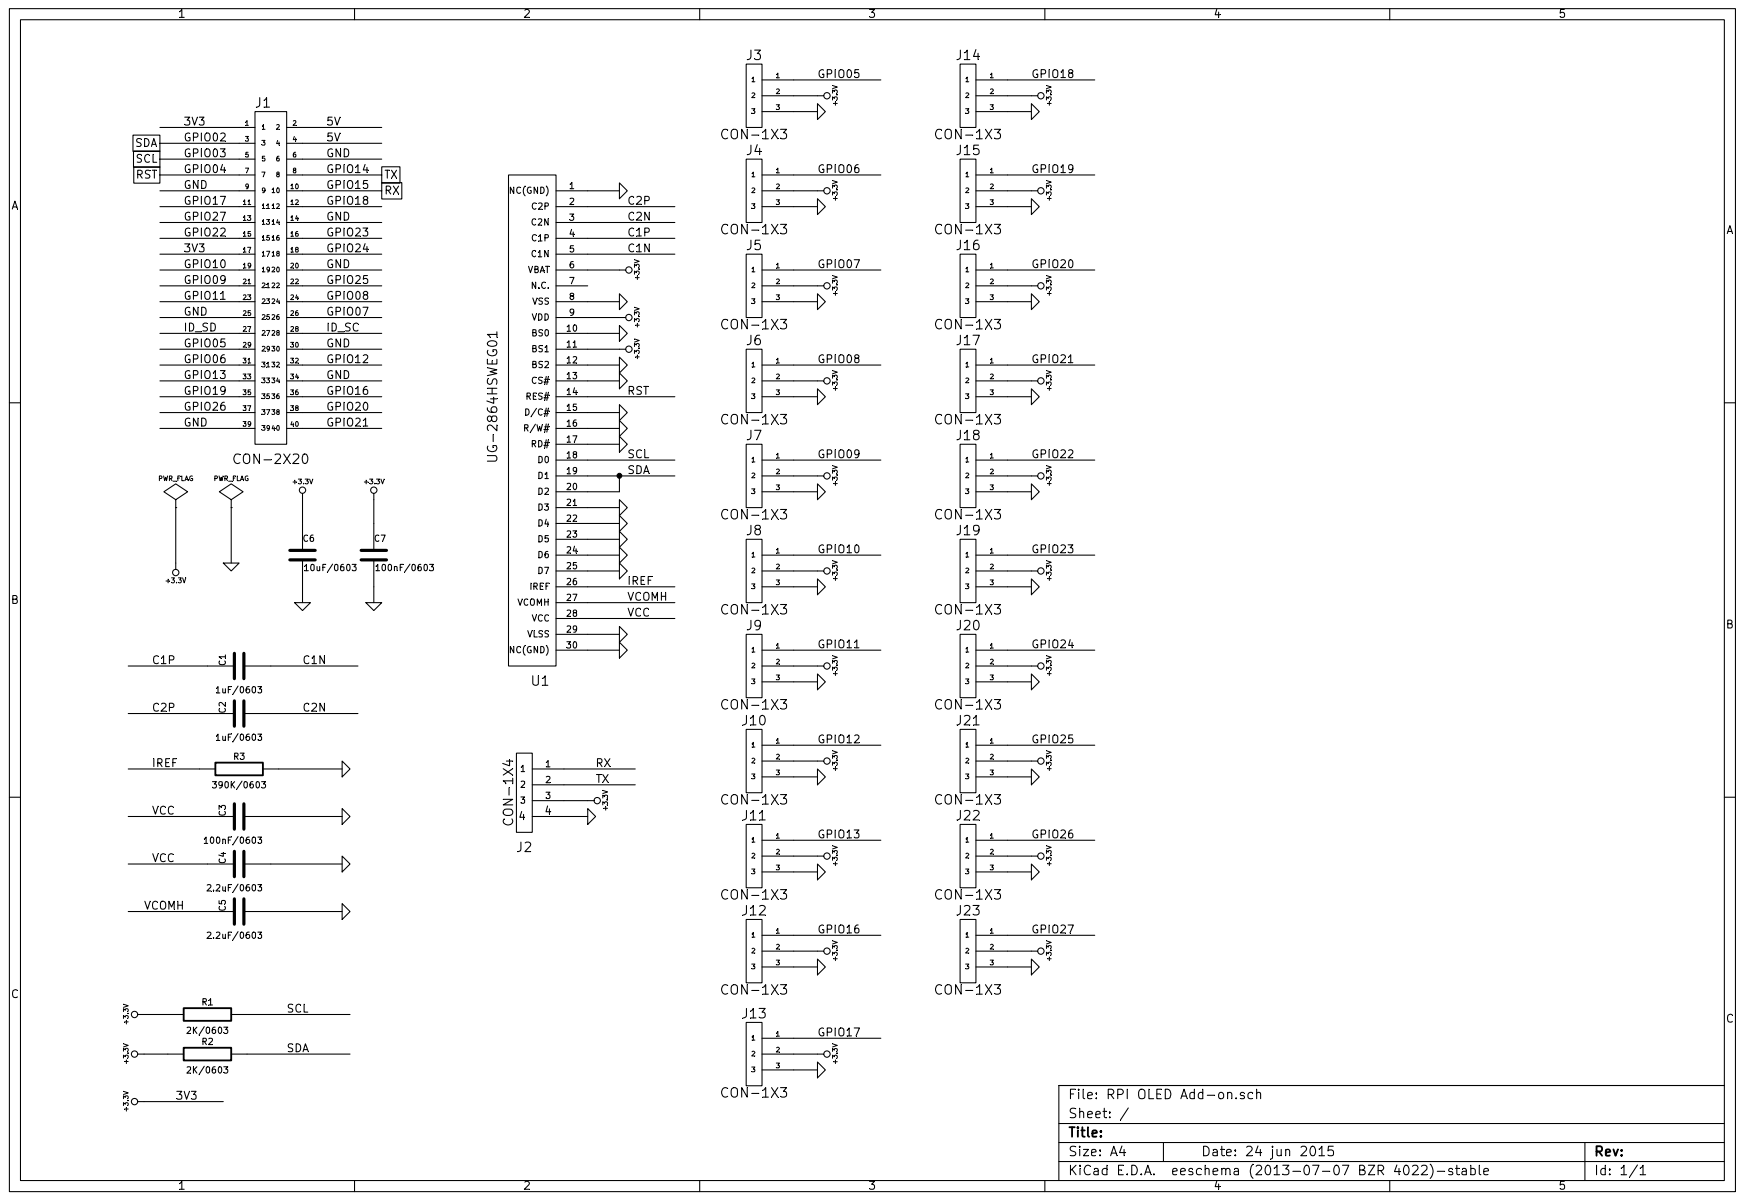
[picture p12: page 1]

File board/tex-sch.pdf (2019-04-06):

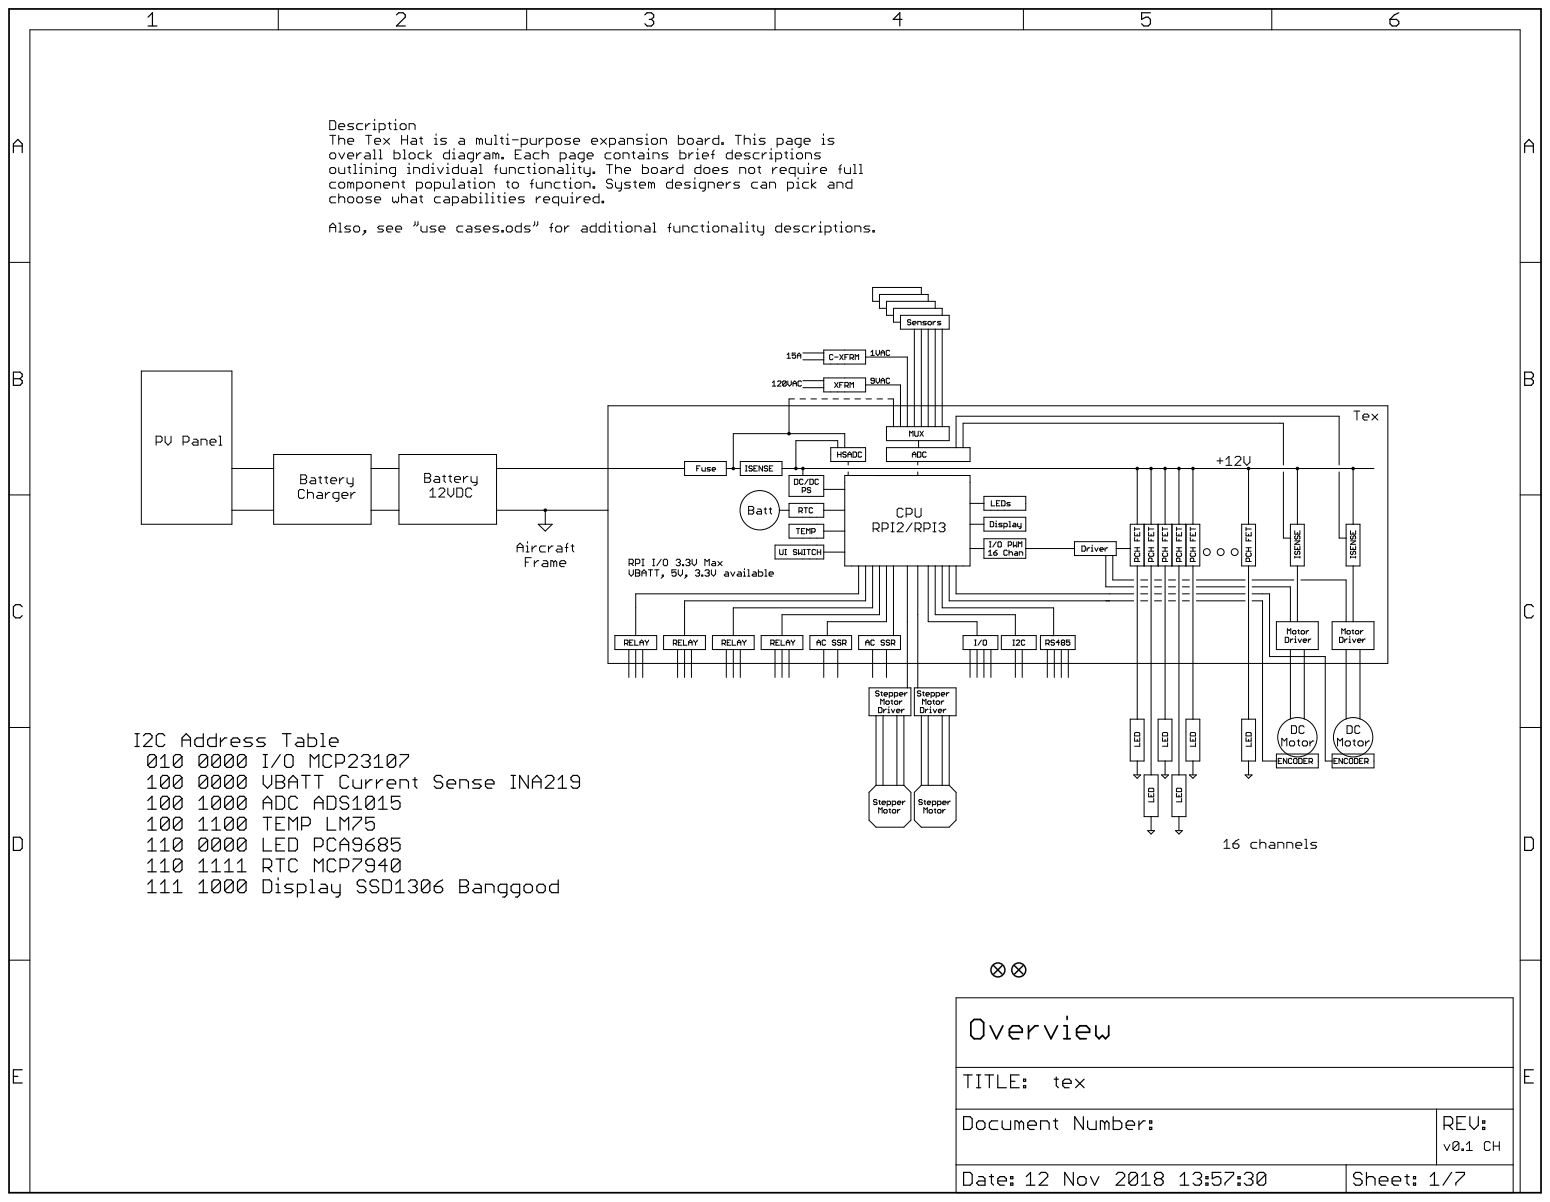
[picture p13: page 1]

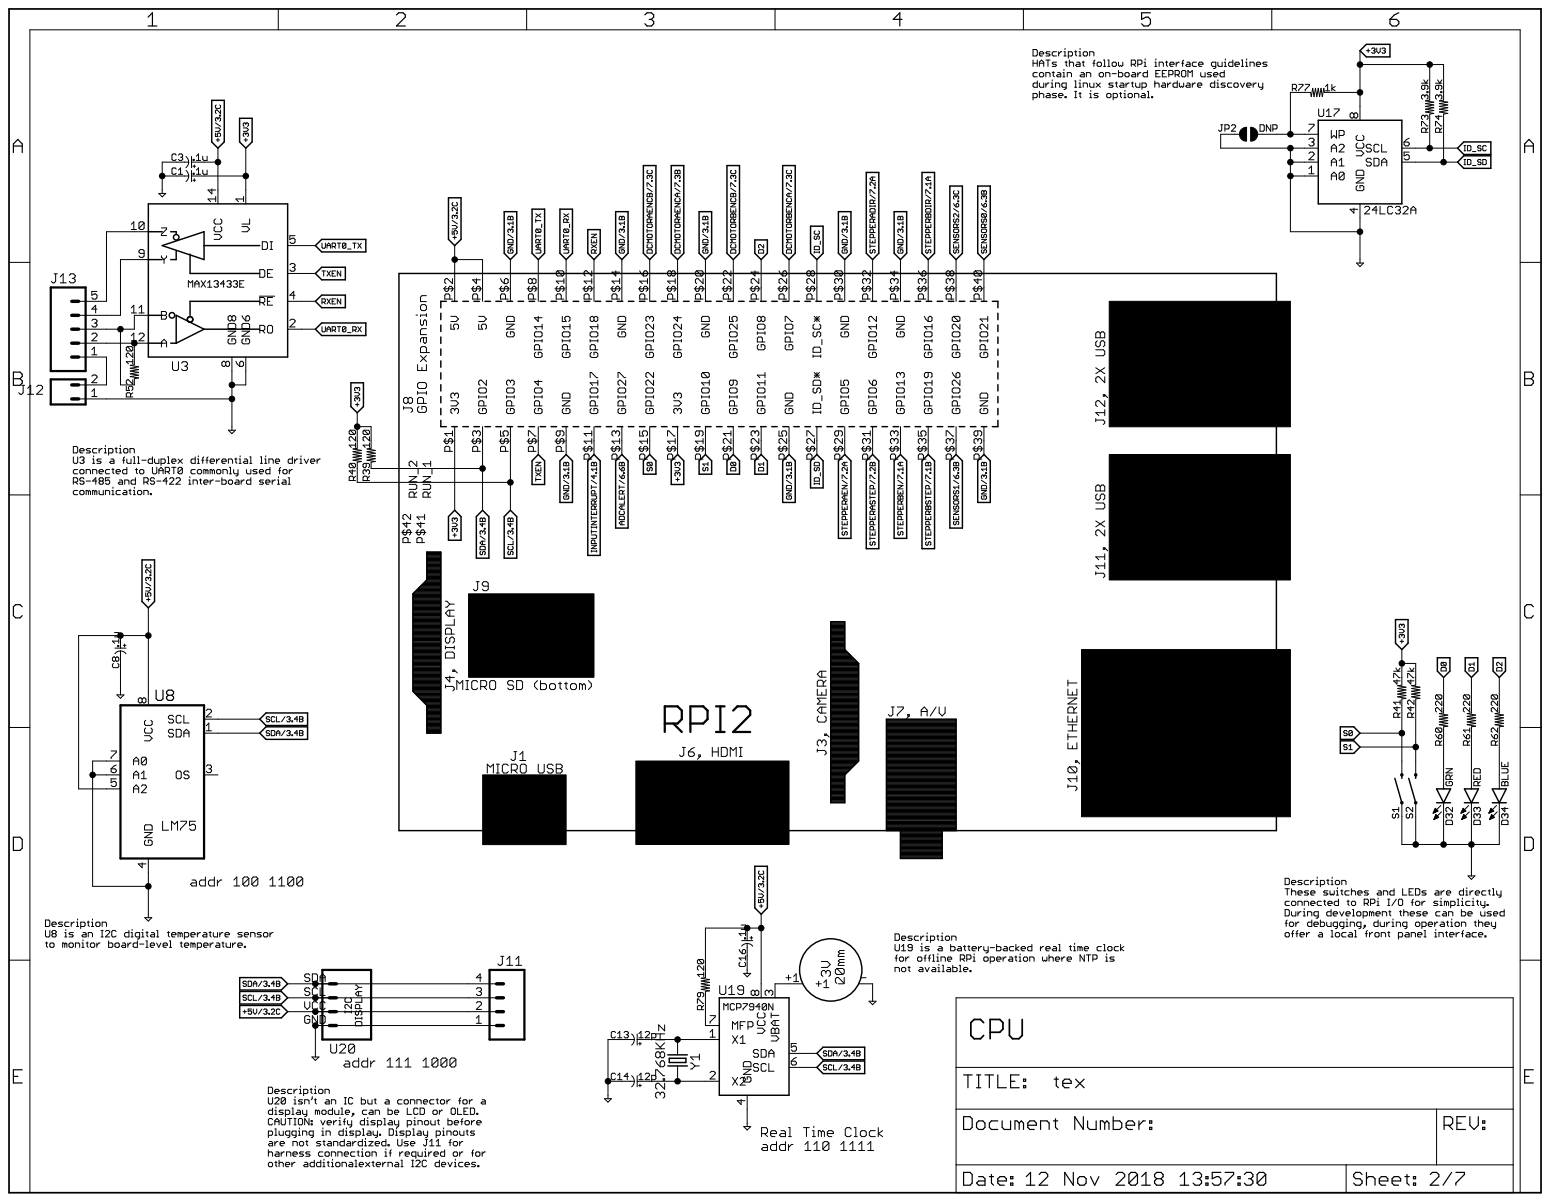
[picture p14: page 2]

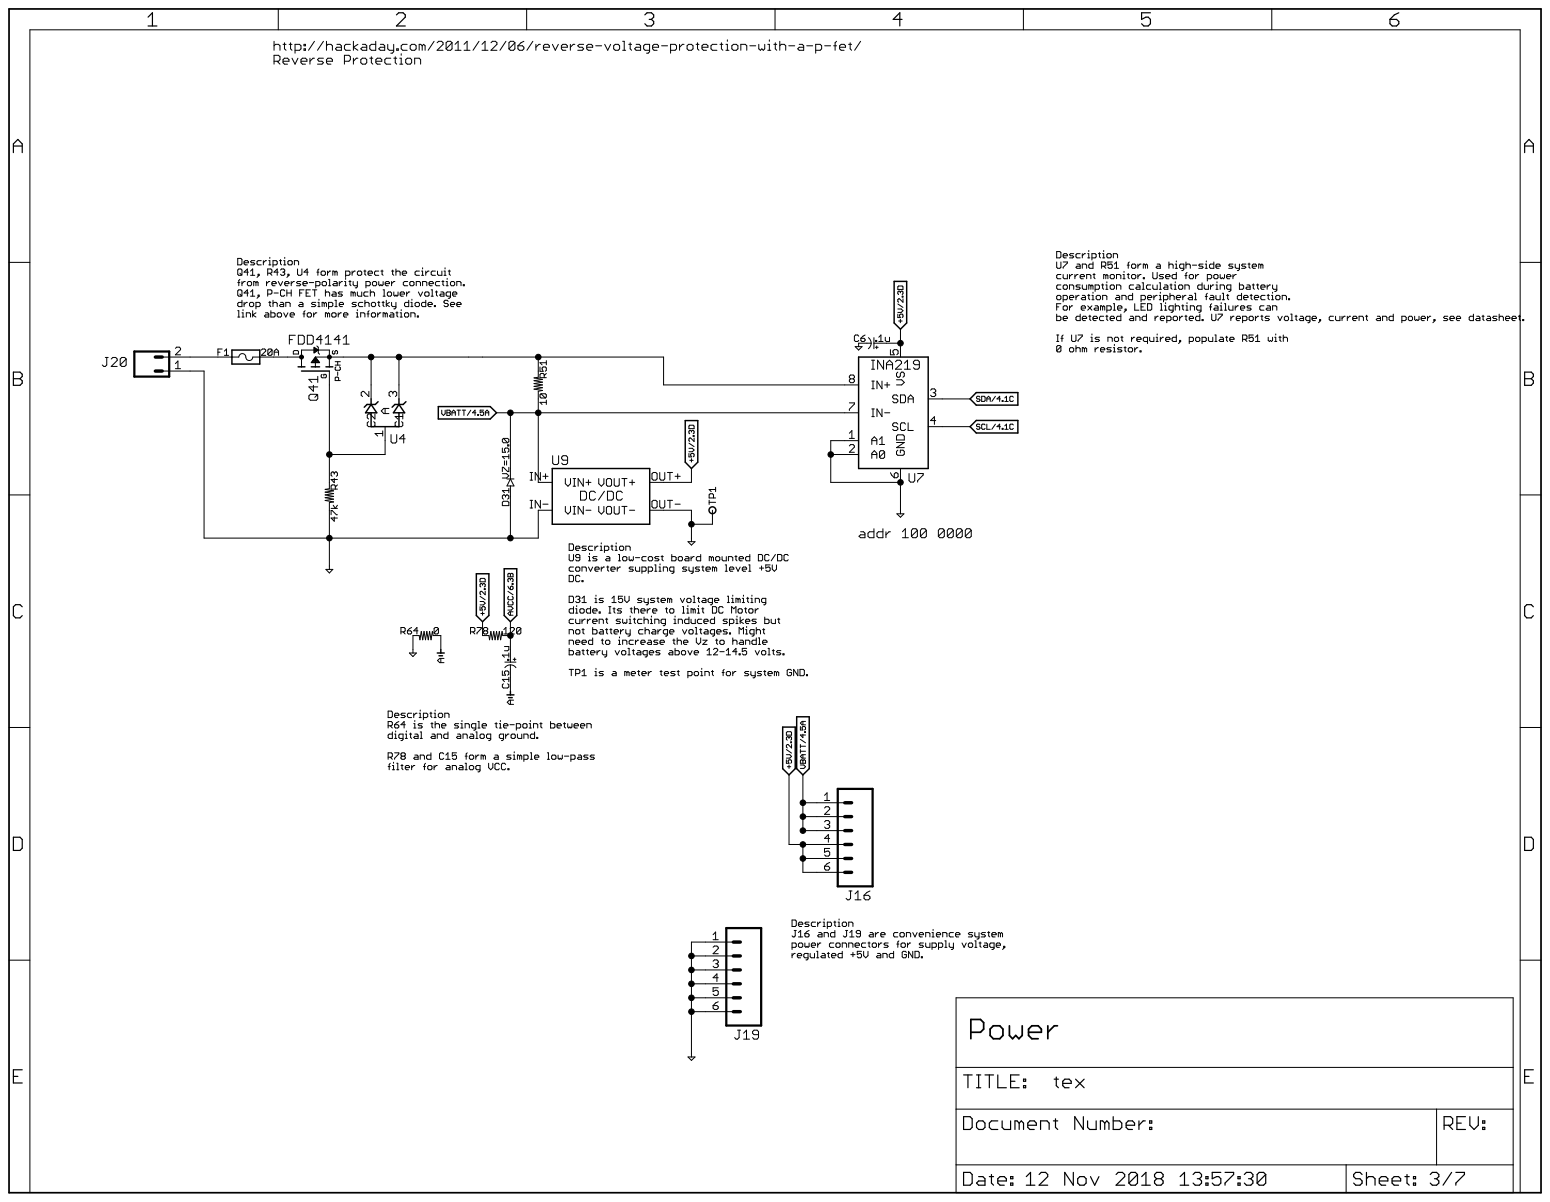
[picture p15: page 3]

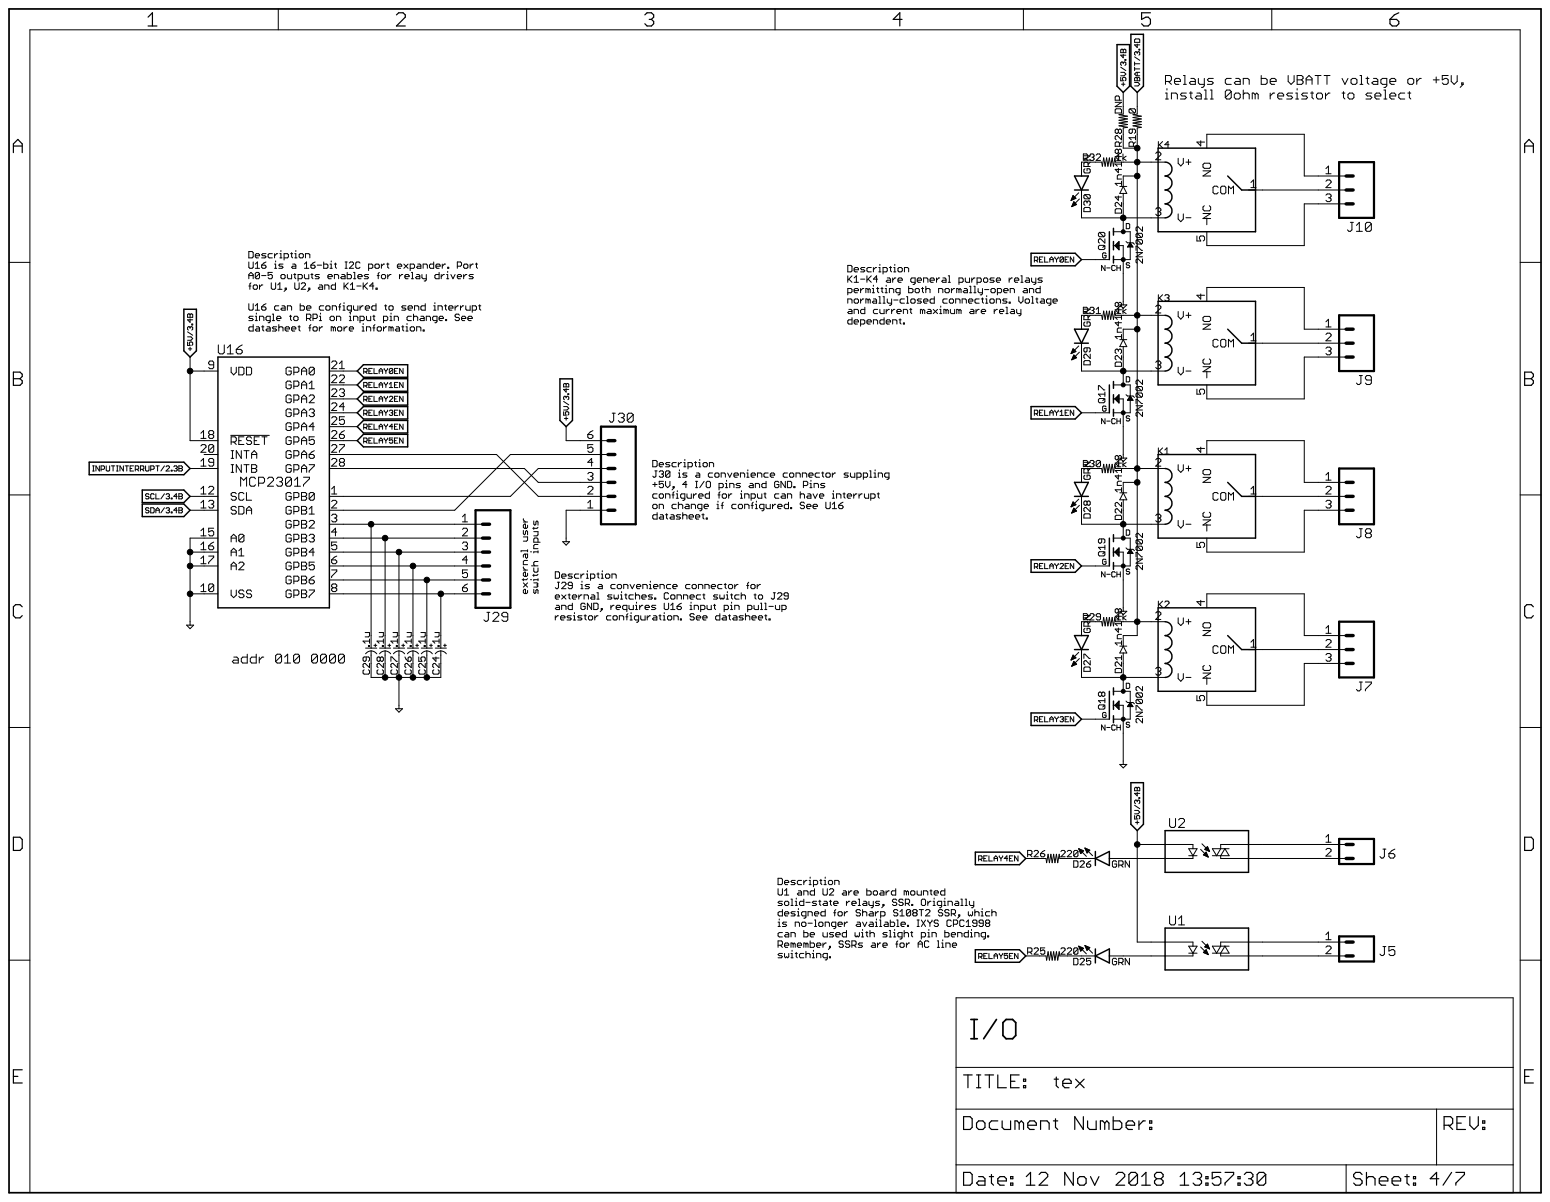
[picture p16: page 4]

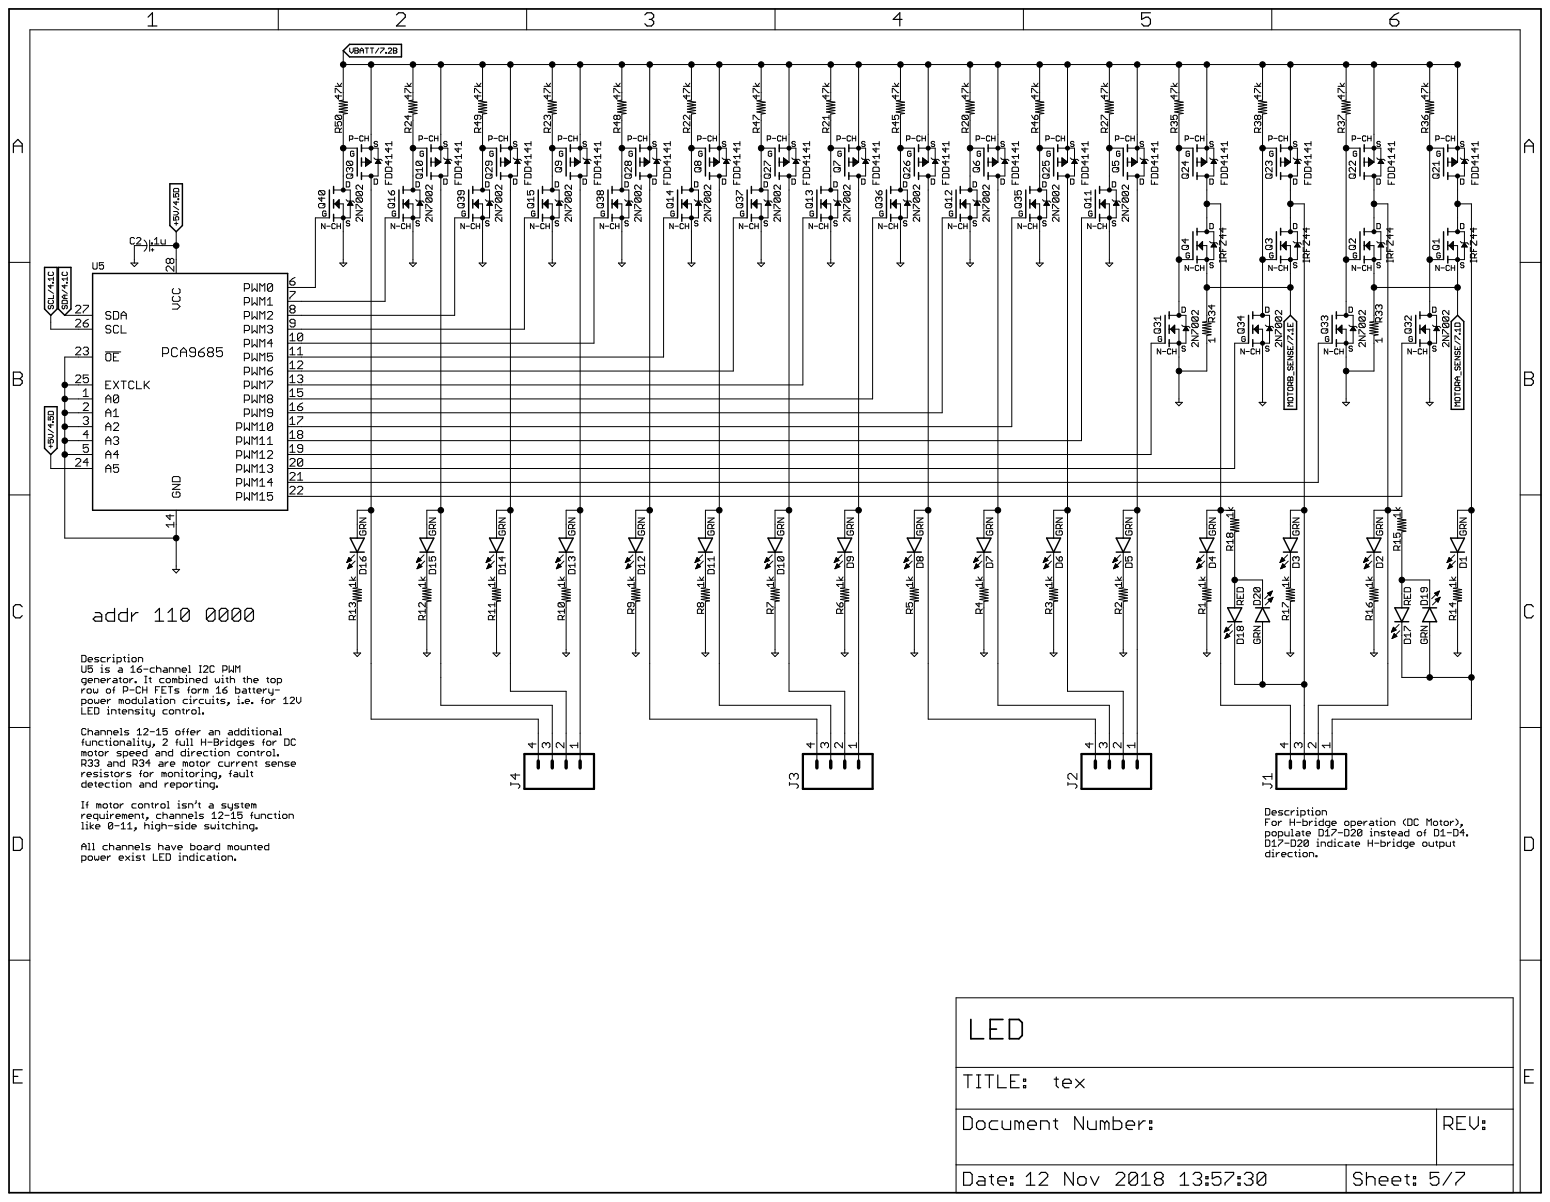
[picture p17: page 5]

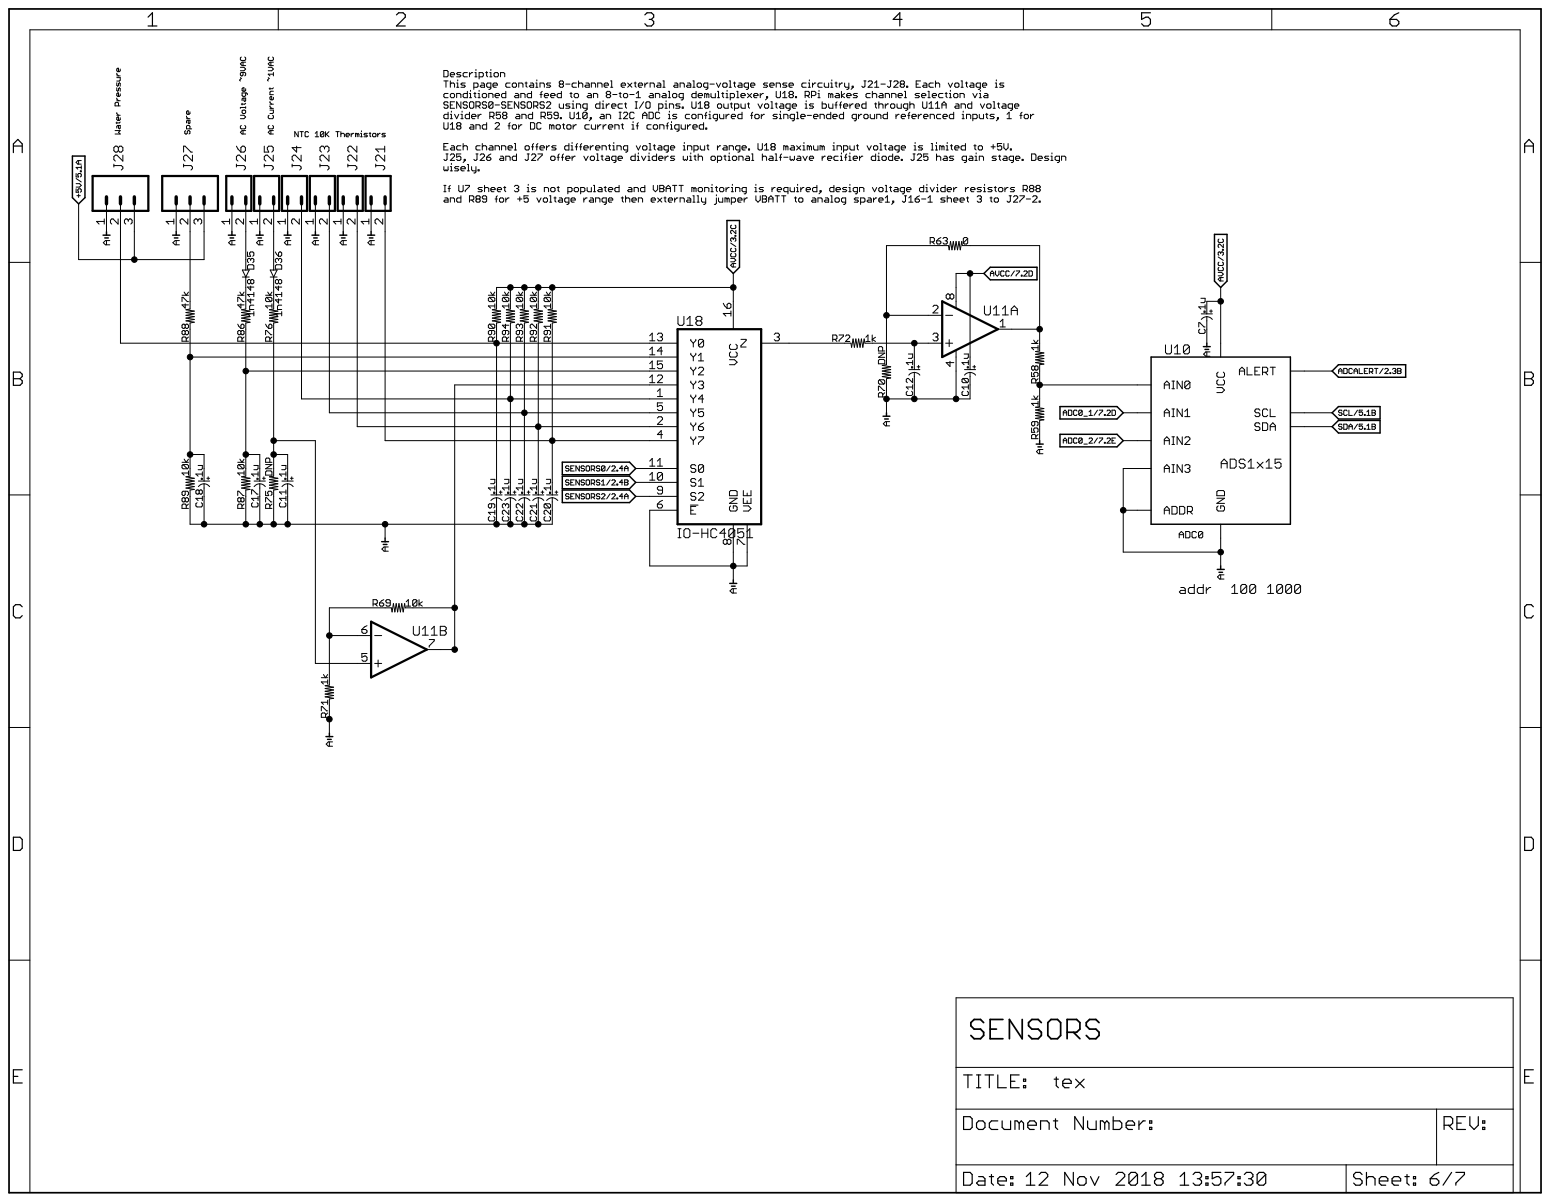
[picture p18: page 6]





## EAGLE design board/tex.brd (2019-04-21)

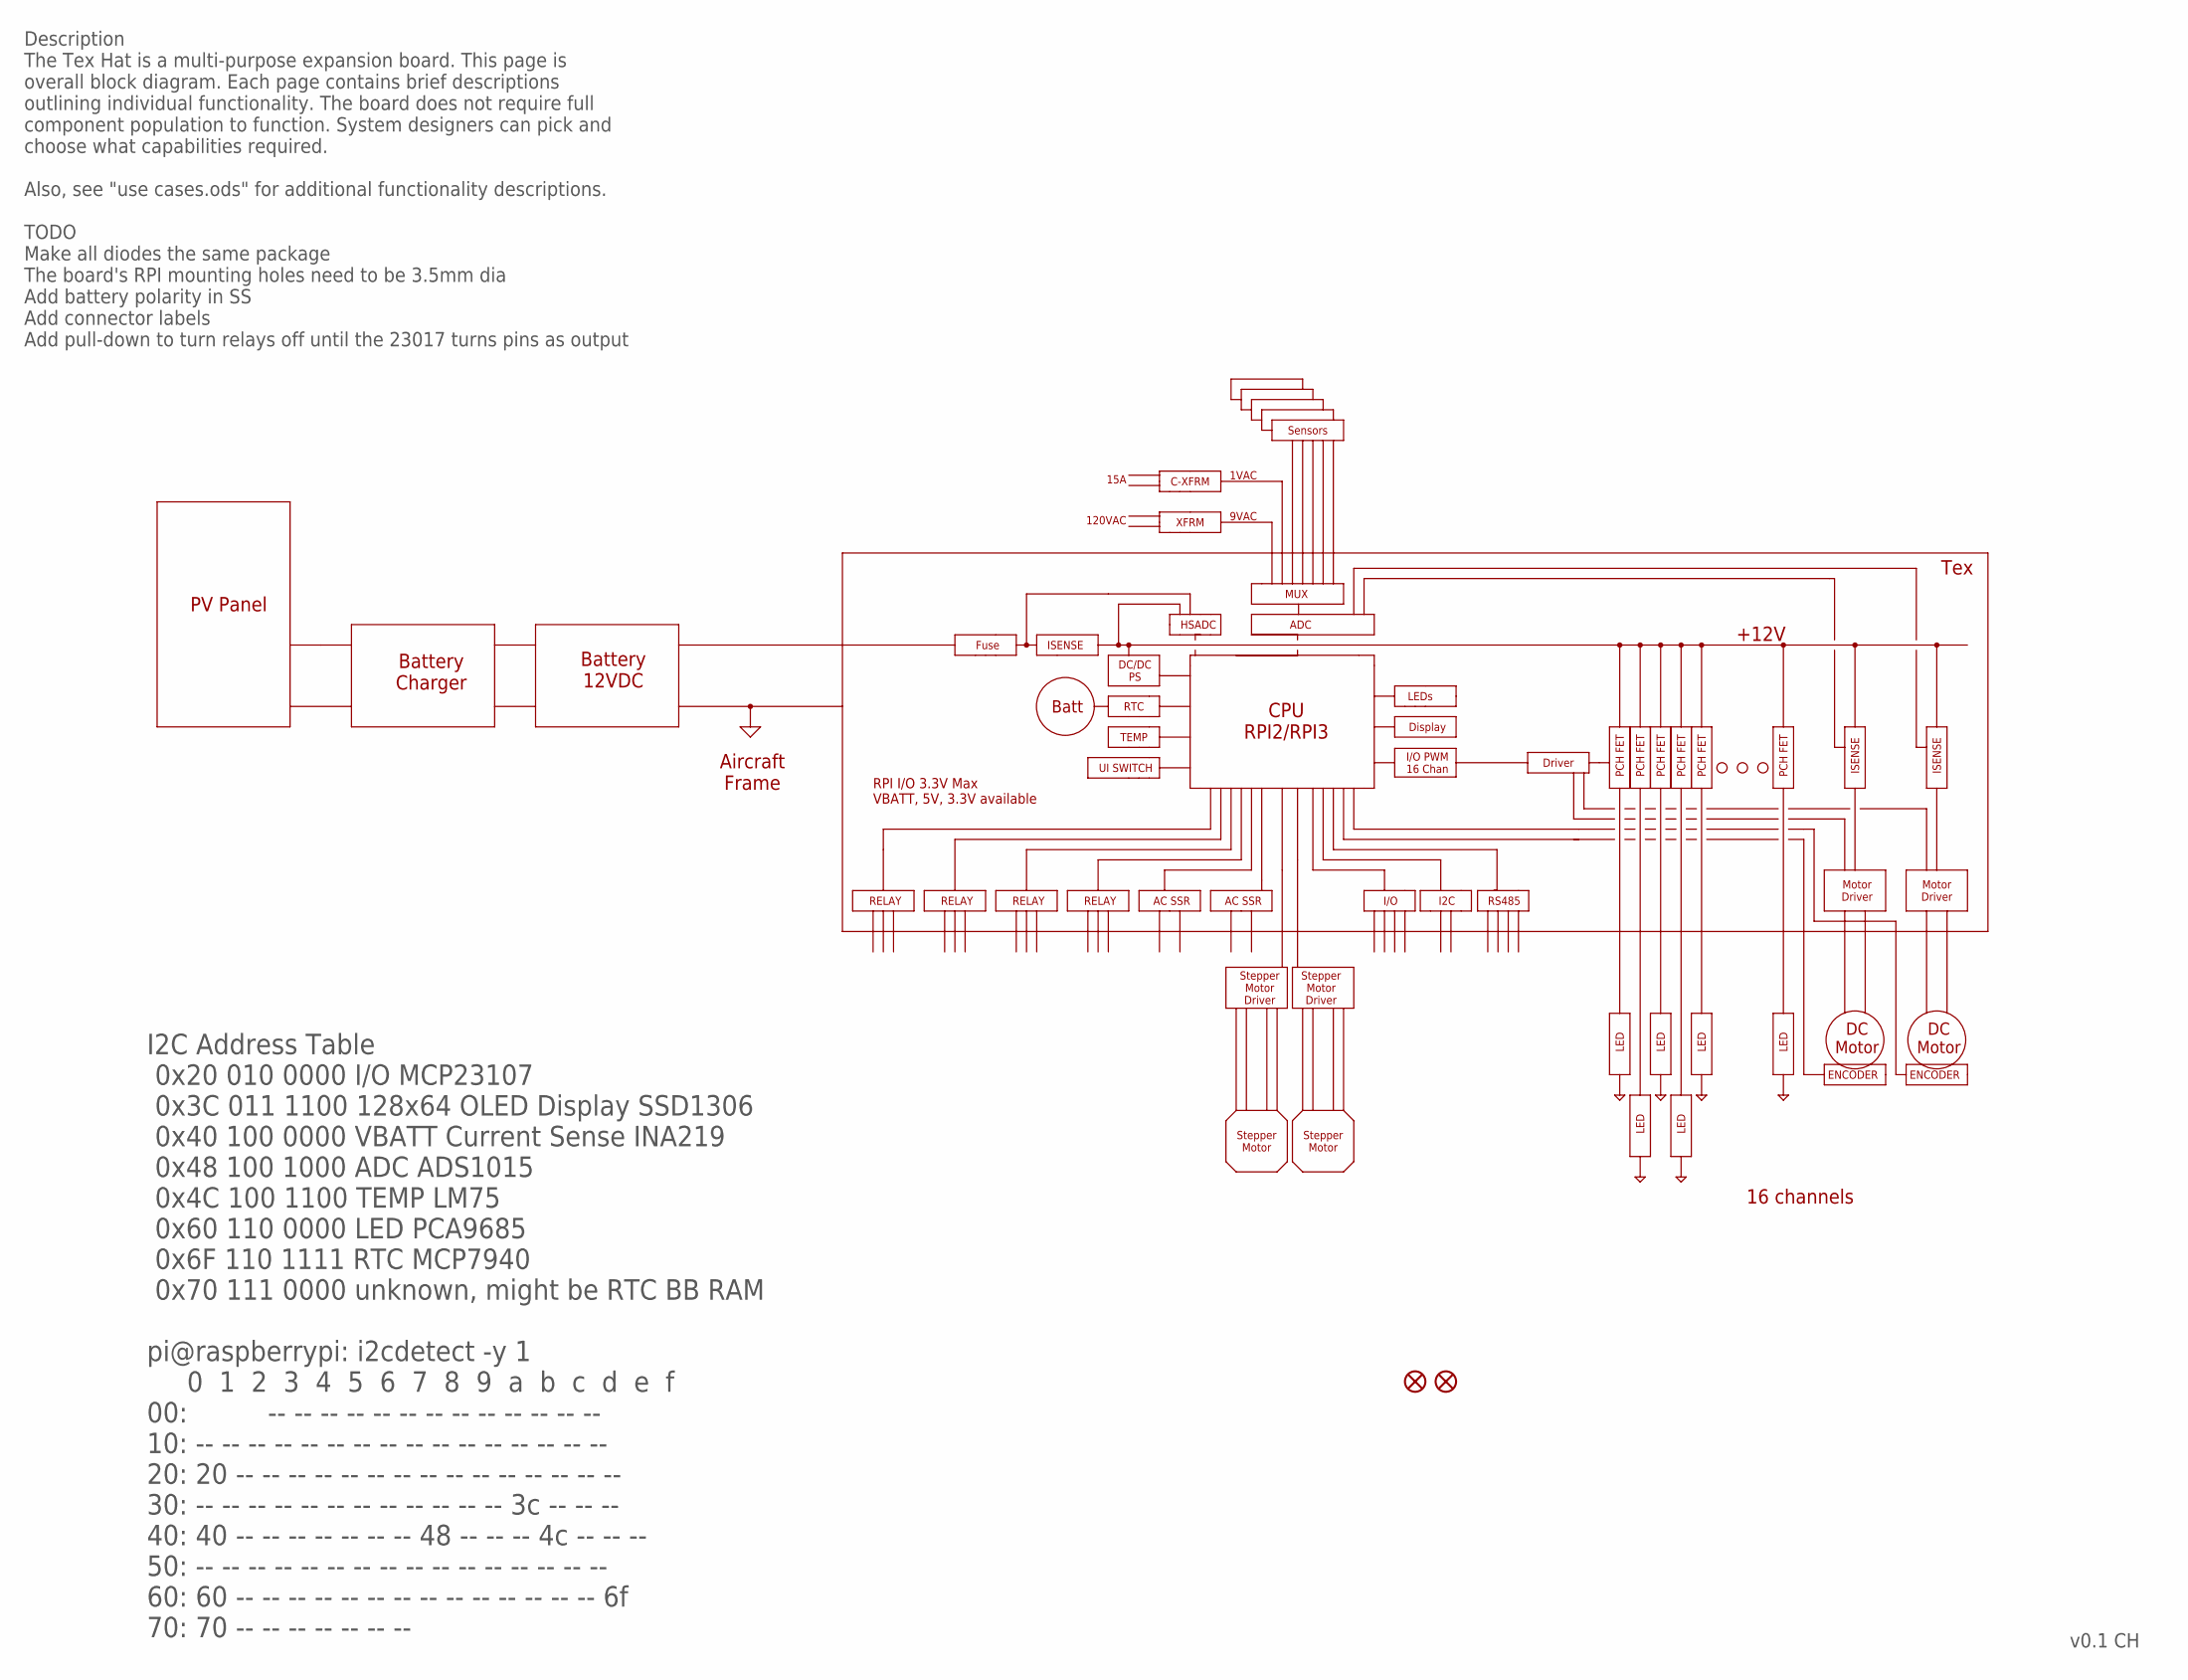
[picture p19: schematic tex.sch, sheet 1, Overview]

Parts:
JP1, JP3: FIDUCIALUFIDUCIAL; MICRO-FIDUCIAL

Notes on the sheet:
PV Panel
Battery Charger
Battery 12VDC
Aircraft Frame
Tex
DC/DC PS
CPU RPI2/RPI3
Display
+12V
I/O PWM 16 Chan
PCH FET
Driver
LED
RELAY
Motor Driver
Stepper Motor Driver
DC Motor
Stepper Motor
16 channels
TEMP
ADC
Fuse
AC SSR
I/O
LEDs
RPI I/O 3.3V Max VBATT, 5V, 3.3V available
I2C
HSADC
RS485
RTC
Sensors
MUX
ISENSE
Description The Tex Hat is a multi-purpose expansion board. This page is overall block diagram. Each page contains brief descriptions outlining individual functionality. The board does not require full component population to function. System designers can pick and choose what capabilities required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
I2C Address Table 0x20 010 0000 I/O MCP23107 0x3C 011 1100 128x64 OLED Display SSD1306 0x40 100 0000 VBATT Current Sense INA219 0x48 100 1000 ADC ADS1015 0x4C 100 1100 TEMP LM75 0x60 110 0000 LED PCA9685 0x6F 110 1111 RTC MCP7940 0x70 111 0000 unknown, might be RTC BB RAM pi@raspberrypi: i2cdetect 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
Batt
UI SWITCH
XFRM
120VAC
9VAC

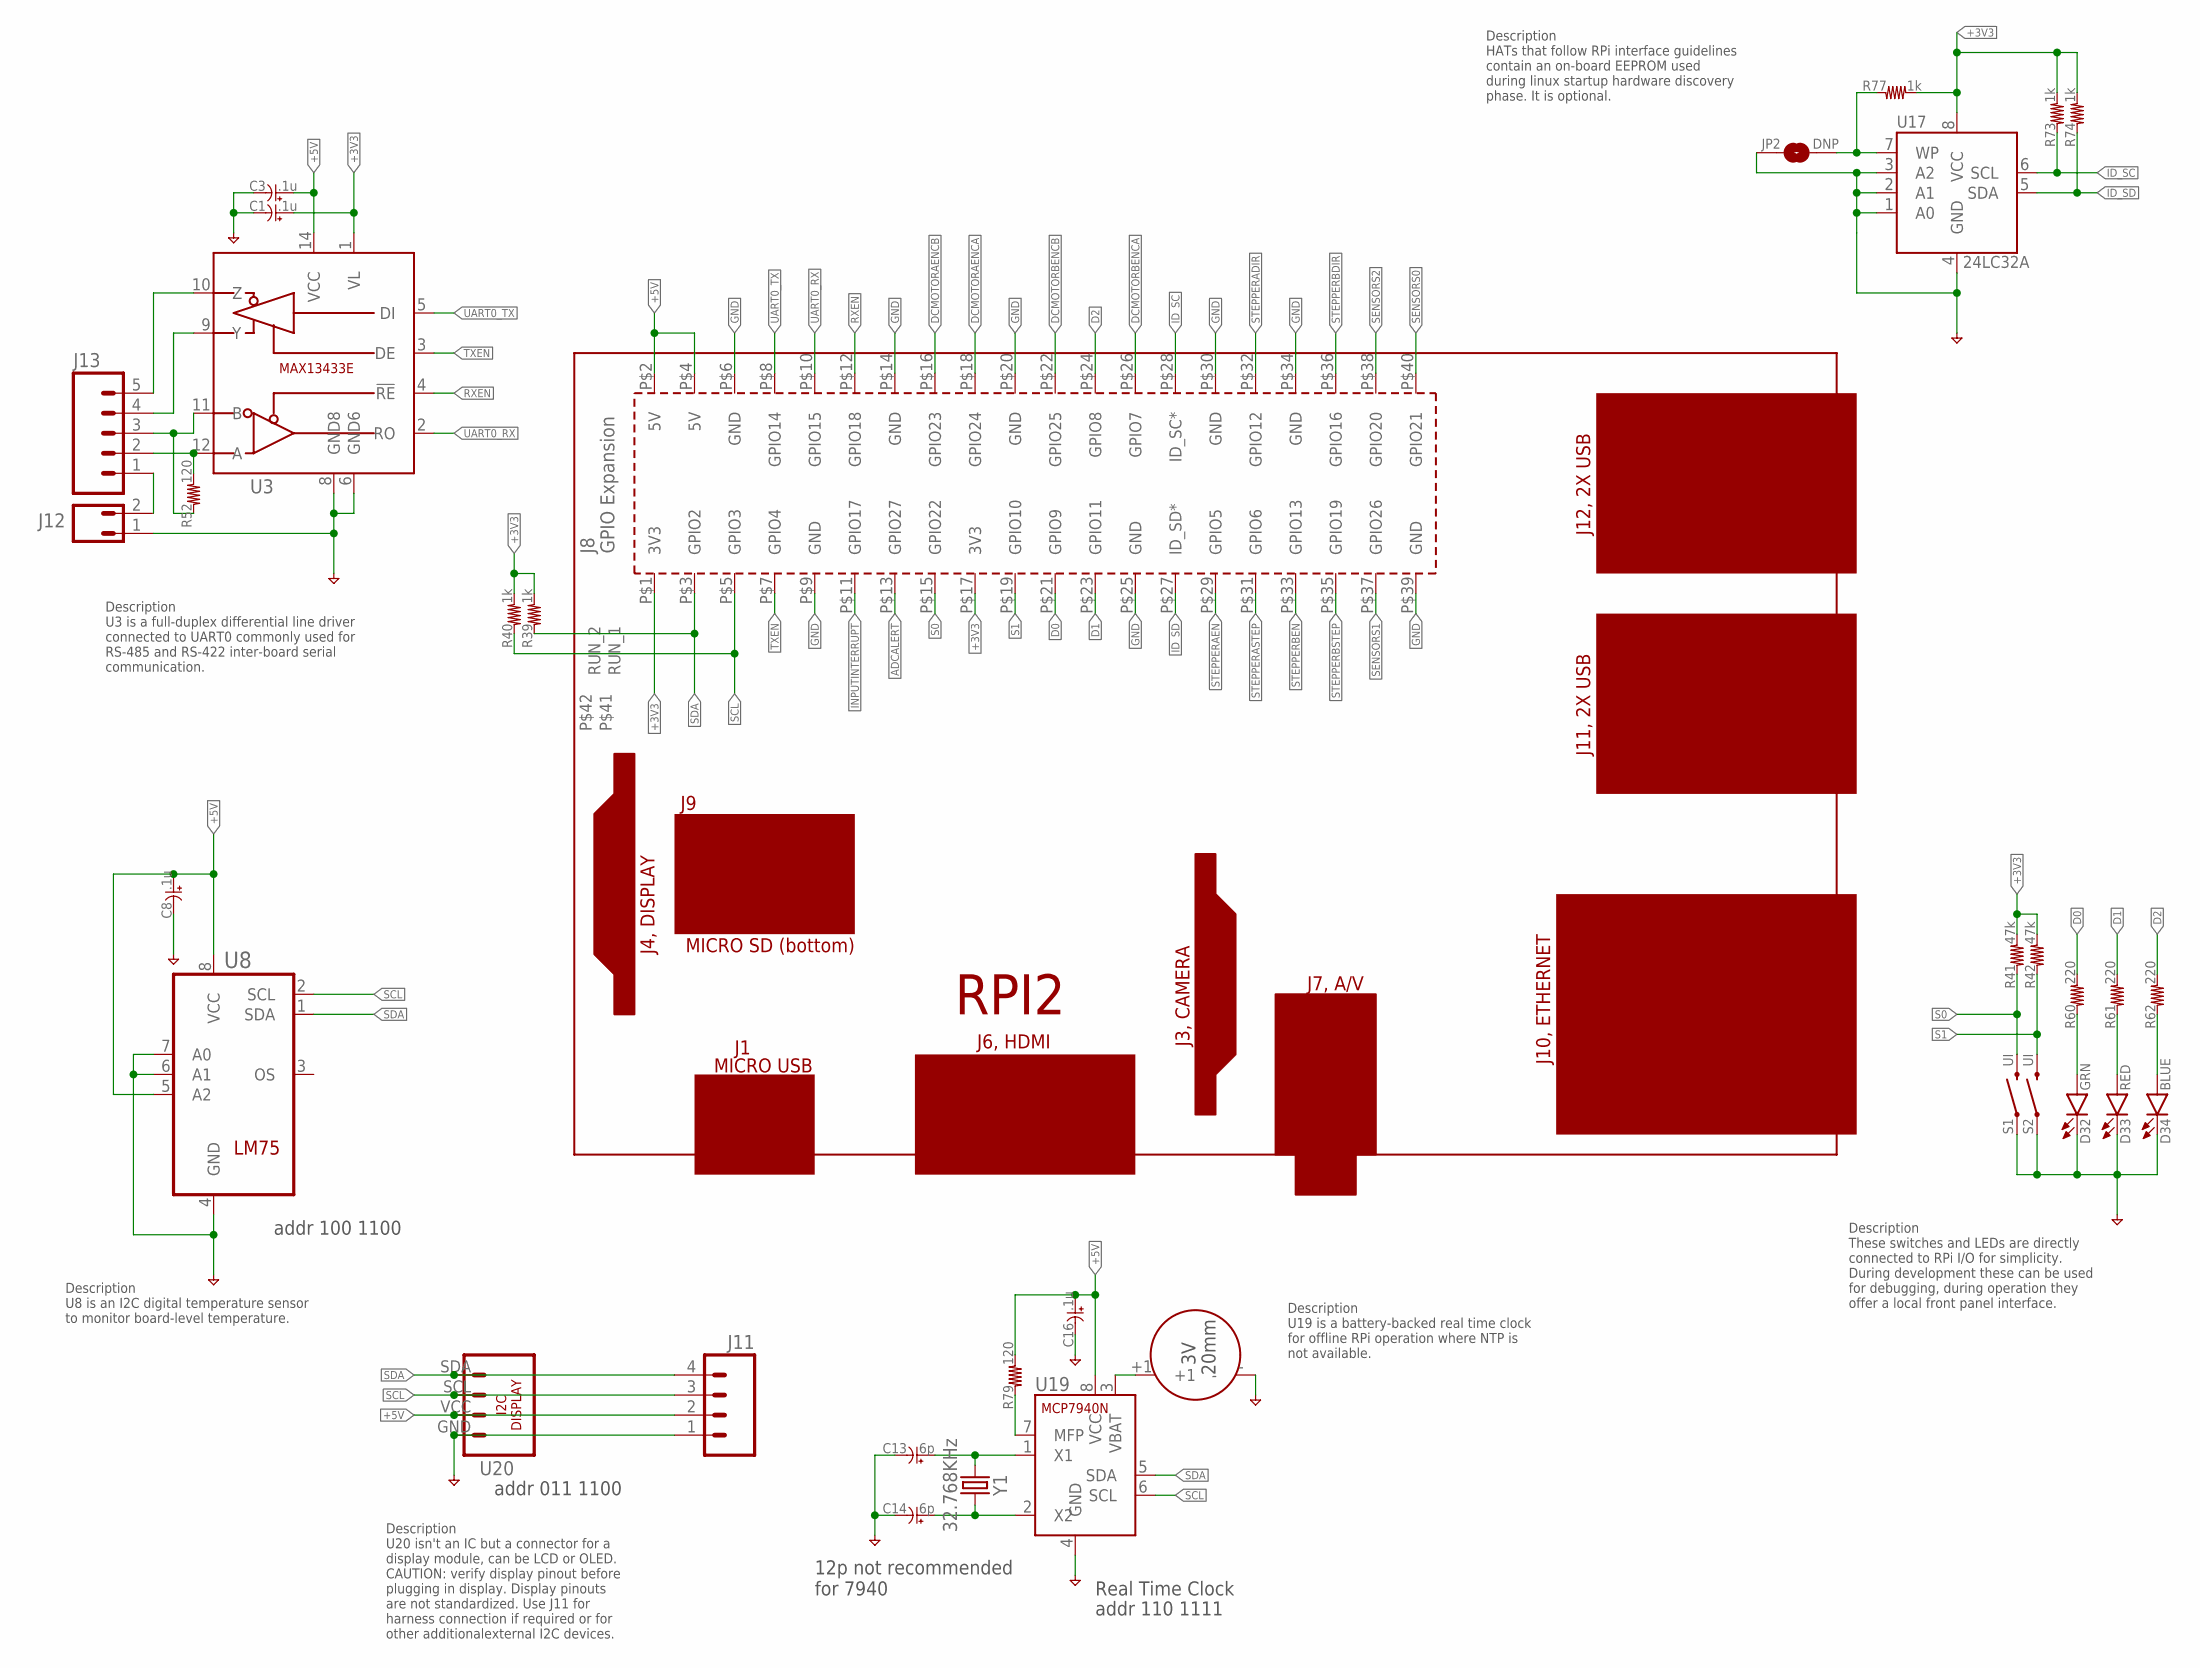
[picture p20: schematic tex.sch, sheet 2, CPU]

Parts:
B1: CR2032; BAT-HLD-001
C1, C3, C8, C16: .1u; C0603
C13, C14: 6p; C0603
D32: GRN; LED0603
D33: RED; LED0603
D34: BLUE; LED0603
J11: CONN-04-0.1; 1X04
J12: CONN-02-0.1; 1X02
J13: CONN-05-PLUGIN-SCREW; CONN-3.81MM-KF2EDG-5
JP2: DNP; PAD-JUMPER-2-NO_NO_SILK
PCB1: BOARD-RPI2
R39, R40, R73, R74, R77: 1k; R0603
R41, R42: 47k; R0603
R52, R79: 120; R0603
R60, R61, R62: 220; R0603
S1, S2: UI; TACTILE-SWITCH-6MMX3.5MM
U3: MAX13433E; SO14
U8: LM75; SO08
U17: 24LC32A; SO08
U19: MCP7940N; SO08
U20: DISP-I2C-4PIN; DISP-I2C-4PIN-0.96
Y1: 32.768KHz; ABS25

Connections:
+3V3: C1.1, PCB1.P$1 (3V3), PCB1.P$17 (3V3), R39.2, R40.2, R41.2, R42.2, R73.2, R74.2, R77.2, U3.1 (VL), U17.8 (VCC)
+5V: C3.1, C8.1, C16.1, J11.2, PCB1.P$2 (5V), PCB1.P$4 (5V), R79.2, U3.14 (VCC), U8.5 (A2), U8.8 (VCC), U19.8 (VCC), U20.VCC; also elsewhere on the board
ADCALERT: PCB1.P$13 (GPIO27); also elsewhere on the board
D0: PCB1.P$21 (GPIO9), R60.2
D1: PCB1.P$23 (GPIO11), R61.2
D2: PCB1.P$24 (GPIO8), R62.2
DCMOTORAENCA: PCB1.P$18 (GPIO24); also elsewhere on the board
DCMOTORAENCB: PCB1.P$16 (GPIO23); also elsewhere on the board
DCMOTORBENCA: PCB1.P$26 (GPIO7); also elsewhere on the board
DCMOTORBENCB: PCB1.P$22 (GPIO25); also elsewhere on the board
GND: B1.-, C1.2, C3.2, C8.2, C13.2, C14.2, C16.2, D32.C, D33.C, D34.C, J11.1, J12.1, JP2.1, PCB1.P$6 (GND), PCB1.P$9 (GND), PCB1.P$14 (GND), PCB1.P$20 (GND), PCB1.P$25 (GND), PCB1.P$30 (GND), PCB1.P$34 (GND), PCB1.P$39 (GND), S1.P$1 (1), S2.P$1 (1), U3.6 (GND6), U3.8 (GND8), U8.4 (GND), U8.6 (A1), U8.7 (A0), U17.1 (A0), U17.2 (A1), U17.3 (A2), U17.4 (GND), U19.4 (GND), U20.GND; also elsewhere on the board
ID_SC: PCB1.P$28 (ID_SC*), R73.1, U17.6 (SCL)
ID_SD: PCB1.P$27 (ID_SD*), R74.1, U17.5 (SDA)
INPUTINTERRUPT: PCB1.P$11 (GPIO17); also elsewhere on the board
unnamed: C13.1, U19.1 (X1), Y1.1
unnamed: C14.1, U19.2 (X2), Y1.4 (2)
unnamed: J13.2, R52.2, U3.12 (A)
unnamed: J13.3, R52.1, U3.11 (B)
unnamed: J13.4, U3.9 (Y)
unnamed: J13.5, U3.10 (Z)
unnamed: J12.2, J13.1
unnamed: D32.A, R60.1
unnamed: D33.A, R61.1
unnamed: D34.A, R62.1
unnamed: JP2.2, R77.1, U17.7 (WP)
unnamed: B1.+1, U19.3 (VBAT)
unnamed: R79.1, U19.7 (MFP)
RXEN: PCB1.P$12 (GPIO18), U3.4 (!RE)
S0: PCB1.P$15 (GPIO22), R41.1, S1.P$2 (2)
S1: PCB1.P$19 (GPIO10), R42.1, S2.P$2 (2)
SCL: J11.3, PCB1.P$5 (GPIO3), R40.1, U8.2 (SCL), U19.6 (SCL), U20.SCL; also elsewhere on the board
SDA: J11.4, PCB1.P$3 (GPIO2), R39.1, U8.1 (SDA), U19.5 (SDA), U20.SDA; also elsewhere on the board
SENSORS0: PCB1.P$40 (GPIO21); also elsewhere on the board
SENSORS1: PCB1.P$37 (GPIO26); also elsewhere on the board
SENSORS2: PCB1.P$38 (GPIO20); also elsewhere on the board
STEPPERADIR: PCB1.P$32 (GPIO12); also elsewhere on the board
STEPPERAEN: PCB1.P$29 (GPIO5); also elsewhere on the board
STEPPERASTEP: PCB1.P$31 (GPIO6); also elsewhere on the board
STEPPERBDIR: PCB1.P$36 (GPIO16); also elsewhere on the board
STEPPERBEN: PCB1.P$33 (GPIO13); also elsewhere on the board
STEPPERBSTEP: PCB1.P$35 (GPIO19); also elsewhere on the board
TXEN: PCB1.P$7 (GPIO4), U3.3 (DE)
UART0_RX: PCB1.P$10 (GPIO15), U3.2 (RO)
UART0_TX: PCB1.P$8 (GPIO14), U3.5 (DI)

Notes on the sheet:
Real Time Clock
addr 100 1100
addr 110 1111
addr 011 1100
Description U3 is a full-duplex differential line driver connected to UART0 commonly used for RS-485 and RS-422 inter-board serial communication.
Description U8 is an I2C digital temperature sensor to monitor board-level temperature.
Description U20 isn't an IC but a connector for a display module, can be LCD or OLED. CAUTION: verify display pinout before plugging in display. Display pinouts are not standardized. Use J11 for harness connection if required or for other additionalexternal I2C devices.
Description U19 is a battery-backed real time clock for offline RPi operation where NTP is not available.
Description These switches and LEDs are directly connected to RPi I/O for simplicity. During development these can be used for debugging, during operation they offer a local front panel interface.
Description HATs that follow RPi interface guidelines contain an on-board EEPROM used during linux startup hardware discovery phase. It is optional.
12p not recommended for 7940

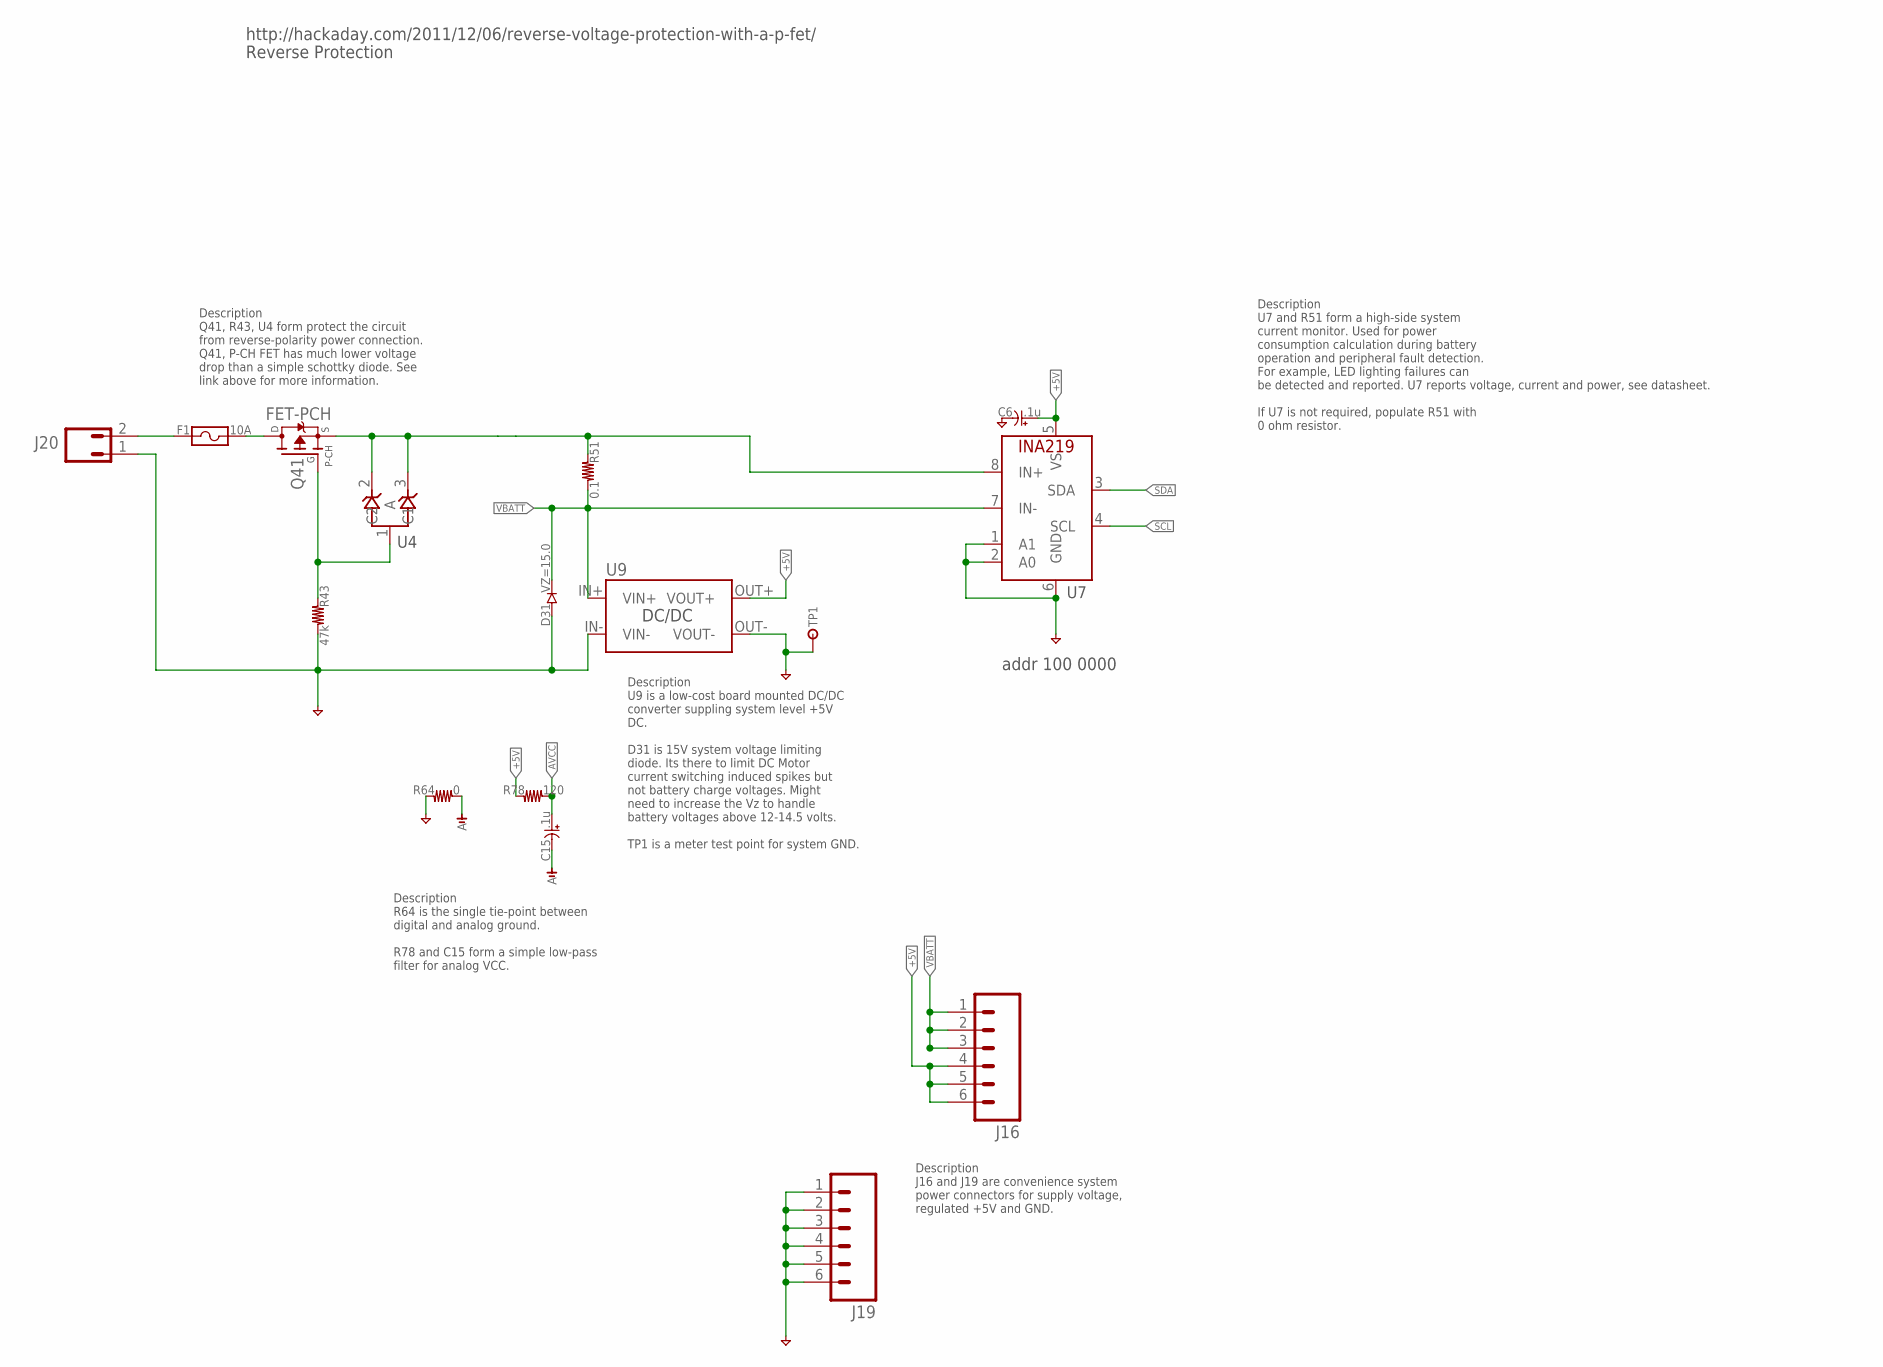
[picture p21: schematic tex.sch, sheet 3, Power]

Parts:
C6, C15: .1u; C0603
D31: VZ=15.0; DO-214AC(SMA)
F1: 10A; 3557-2
J16, J19: CONN-06-PLUGIN-SCREW; CONN-3.81MM-KF2EDG-6
J20: CONN-02-6.35MM; CONN-OSTT702
Q41: FET-PCH; TO252
R43: 47k; R0603
R51: 0.1; R1210
R64: 0; R0603
R78: 120; R0603
TP1: TESTPOINTTHRU; TPTHRU
U4: AZ23C5V1; SOT-23
U7: INA219; SOIC8
U9: DCDC-CONVERTER-LM2577-BOARD; DCDC-LM2577-BOARD

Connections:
+5V: C6.1, J16.4, J16.5, J16.6, R78.1, U7.5 (VS), U9.OUT+ (VOUT+); also elsewhere on the board
AGND: C15.2, R64.2; also elsewhere on the board
AVCC: C15.1, R78.2; also elsewhere on the board
GND: C6.2, D31.A, J19.1, J19.2, J19.3, J19.4, J19.5, J19.6, J20.1, R43.2, R64.1, TP1.1, U7.1 (A1), U7.2 (A0), U7.6 (GND), U9.IN- (VIN-), U9.OUT- (VOUT-); also elsewhere on the board
unnamed: Q41.1 (G), R43.1, U4.1 (A)
unnamed: F1.1@1, F1.1@2, J20.2
unnamed: F1.2@1, F1.2@2, Q41.3 (D)
SCL: U7.4 (SCL); also elsewhere on the board
SDA: U7.3 (SDA); also elsewhere on the board
VBATT: D31.C, J16.1, J16.2, J16.3, R51.2, U7.7 (IN-), U9.IN+ (VIN+); also elsewhere on the board
VBATTISENSE: Q41.2 (S), R51.1, U4.2 (C2), U4.3 (C1), U7.8 (IN+)

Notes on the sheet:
Reverse Protection
http://hackaday.com/2011/12/06/reverse-voltage-protection-with-a-p-fet/
addr 100 0000
Description Q41, R43, U4 form protect the circuit from reverse-polarity power connection. Q41, P-CH FET has much lower voltage drop than a simple schottky diode. See link above for more information.
Description U7 and R51 form a high-side system current monitor. Used for power consumption calculation during battery operation and peripheral fault detection. For example, LED lighting failures can be detected and reported. U7 reports voltage, current and power, see datasheet. If U7 is not require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
Description U9 is a low-cost board mounted DC/DC converter suppling system level +5V DC. D31 is 15V system voltage limiting diode. Its there to limit DC Motor current switching induced spikes but not battery charge voltages. Might need to increase the Vz to handle battery voltages above 12-14.5 vol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
Description R64 is the single tie-point between digital and analog ground. R78 and C15 form a simple low-pass filter for analog VCC.
Description J16 and J19 are convenience system power connectors for supply voltage, regulated +5V and GND.

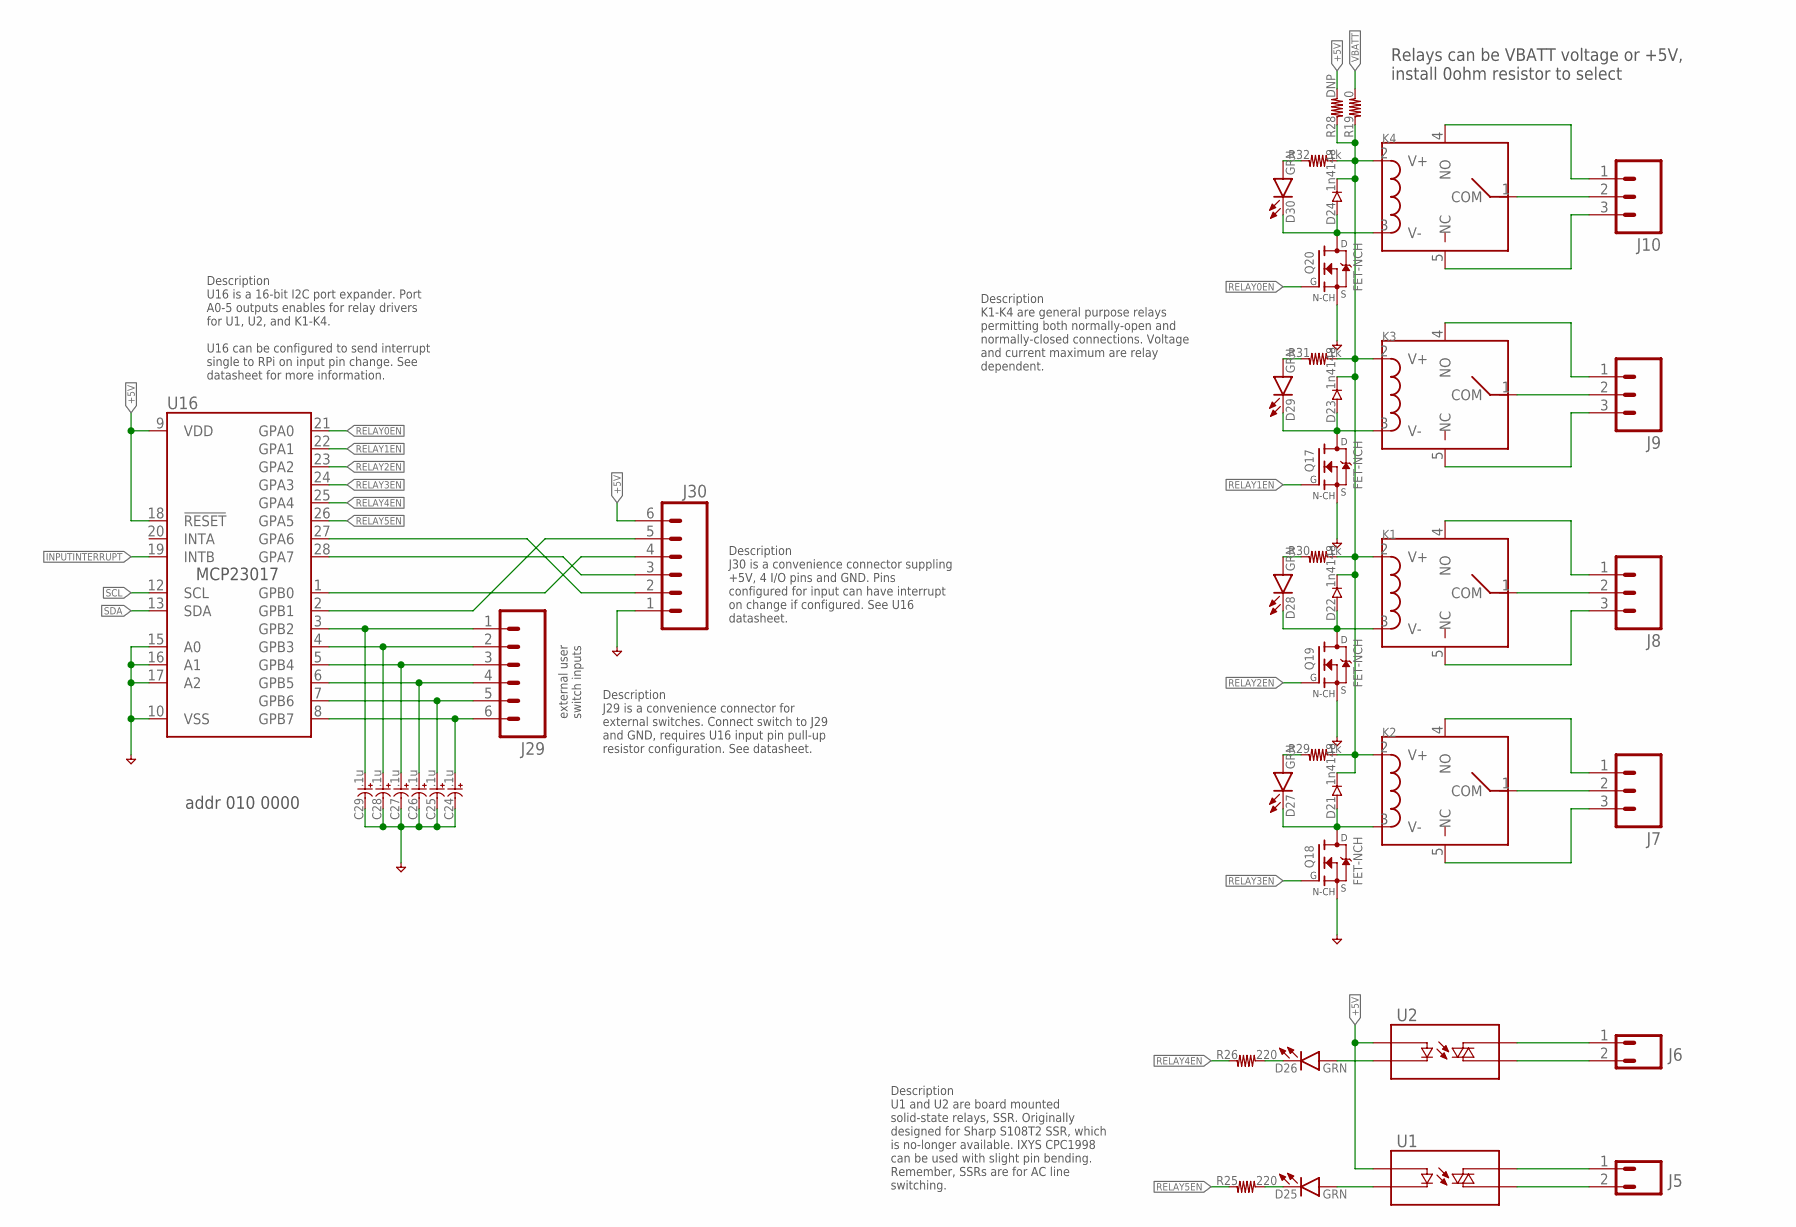
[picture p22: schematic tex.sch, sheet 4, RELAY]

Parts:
C24, C25, C26, C27, C28, C29: .1u; C0603
D21, D22, D23, D24: 1n4148; SOD-523
D25, D26, D27, D28, D29, D30: GRN; LED0603
J5, J6: CONN-02-PLUGIN-SCREW; CONN-3.81MM-KF2EDG-2
J7, J8, J9, J10: CONN-03-PLUGIN-SCREW; CONN-3.81MM-KF2EDG-3
J29, J30: CONN-06-PLUGIN-SCREW; CONN-3.81MM-KF2EDG-6
K1, K2, K3, K4: RELAY-SPST-19X15X15MM; RELAY-SPST-19.0X15.0X15.0MM
Q17, Q18, Q19, Q20: FET-NCH; SOT23-3
R19: 0; R0603
R25, R26: 220; R0603
R28: DNP; R0603
R29, R30, R31, R32: 1k; R0603
U1, U2: RELAY-S108T02PTH; RELAY-S108T02
U16: MCP23017; SO28W

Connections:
+5V: J30.6, R28.2, U1.3 (+), U2.3 (+), U16.9 (VDD), U16.18 (!RESET); also elsewhere on the board
GND: C24.2, C25.2, C26.2, C27.2, C28.2, C29.2, J30.1, Q17.2 (S), Q18.2 (S), Q19.2 (S), Q20.2 (S), U16.10 (VSS), U16.15 (A0), U16.16 (A1), U16.17 (A2); also elsewhere on the board
GND4: D21.A, D27.C, K2.3 (V-), Q18.3 (D)
INPUTINTERRUPT: U16.19 (INTB); also elsewhere on the board
unnamed: J30.2, U16.27 (GPA6)
unnamed: J30.5, U16.2 (GPB1)
unnamed: J30.4, U16.1 (GPB0)
unnamed: J30.3, U16.28 (GPA7)
unnamed: J6.1, U2.1 (T1)
unnamed: C29.1, J29.1, U16.3 (GPB2)
unnamed: C28.1, J29.2, U16.4 (GPB3)
unnamed: C27.1, J29.3, U16.5 (GPB4)
unnamed: C26.1, J29.4, U16.6 (GPB5)
unnamed: C25.1, J29.5, U16.7 (GPB6)
unnamed: C24.1, J29.6, U16.8 (GPB7)
unnamed: J10.2, K4.1 (COM)
unnamed: J10.1, K4.4 (NO)
unnamed: J10.3, K4.5 (NC)
unnamed: D29.A, R31.1
unnamed: D22.A, D28.C, K1.3 (V-), Q19.3 (D)
unnamed: D23.A, D29.C, K3.3 (V-), Q17.3 (D)
unnamed: J9.2, K3.1 (COM)
unnamed: J9.1, K3.4 (NO)
unnamed: J9.3, K3.5 (NC)
unnamed: J8.2, K1.1 (COM)
unnamed: J8.1, K1.4 (NO)
unnamed: J8.3, K1.5 (NC)
unnamed: J7.1, K2.4 (NO)
unnamed: J7.2, K2.1 (COM)
unnamed: J7.3, K2.5 (NC)
unnamed: D21.C, D22.C, D23.C, D24.C, K1.2 (V+), K2.2 (V+), K3.2 (V+), K4.2 (V+), R19.1, R28.1, R29.2, R30.2, R31.2, R32.2
unnamed: D30.A, R32.1
unnamed: D28.A, R30.1
unnamed: D27.A, R29.1
unnamed: D24.A, D30.C, K4.3 (V-), Q20.3 (D)
unnamed: J6.2, U2.2 (T2)
unnamed: J5.1, U1.1 (T1)
unnamed: J5.2, U1.2 (T2)
unnamed: D26.C, R26.2
unnamed: D25.C, R25.2
unnamed: D26.A, U2.4 (-)
unnamed: D25.A, U1.4 (-)
RELAY0EN: Q20.1 (G), U16.21 (GPA0)
RELAY1EN: Q17.1 (G), U16.22 (GPA1)
RELAY2EN: Q19.1 (G), U16.23 (GPA2)
RELAY3EN: Q18.1 (G), U16.24 (GPA3)
RELAY4EN: R26.1, U16.25 (GPA4)
RELAY5EN: R25.1, U16.26 (GPA5)
SCL: U16.12 (SCL); also elsewhere on the board
SDA: U16.13 (SDA); also elsewhere on the board
VBATT: R19.2; also elsewhere on the board

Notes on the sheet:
addr 010 0000
external user switch inputs
Relays can be VBATT voltage or +5V, install 0ohm resistor to select
Description U16 is a 16-bit I2C port expander. Port A0-5 outputs enables for relay drivers for U1, U2, and K1-K4. U16 can be configured to send interrupt single to RPi on input pin change. See datasheet for more information.
Description K1-K4 are general purpose relays permitting both normally-open and normally-closed connections. Voltage and current maximum are relay dependent.
Description J30 is a convenience connector suppling +5V, 4 I/O pins and GND. Pins configured for input can have interrupt on change if configured. See U16 datasheet.
Description J29 is a convenience connector for external switches. Connect switch to J29 and GND, requires U16 input pin pull-up resistor configuration. See datasheet.
Description U1 and U2 are board mounted solid-state relays, SSR. Originally designed for Sharp S108T2 SSR, which is no-longer available. IXYS CPC1998 can be used with slight pin bending. Remember, SSRs are for AC line switching.

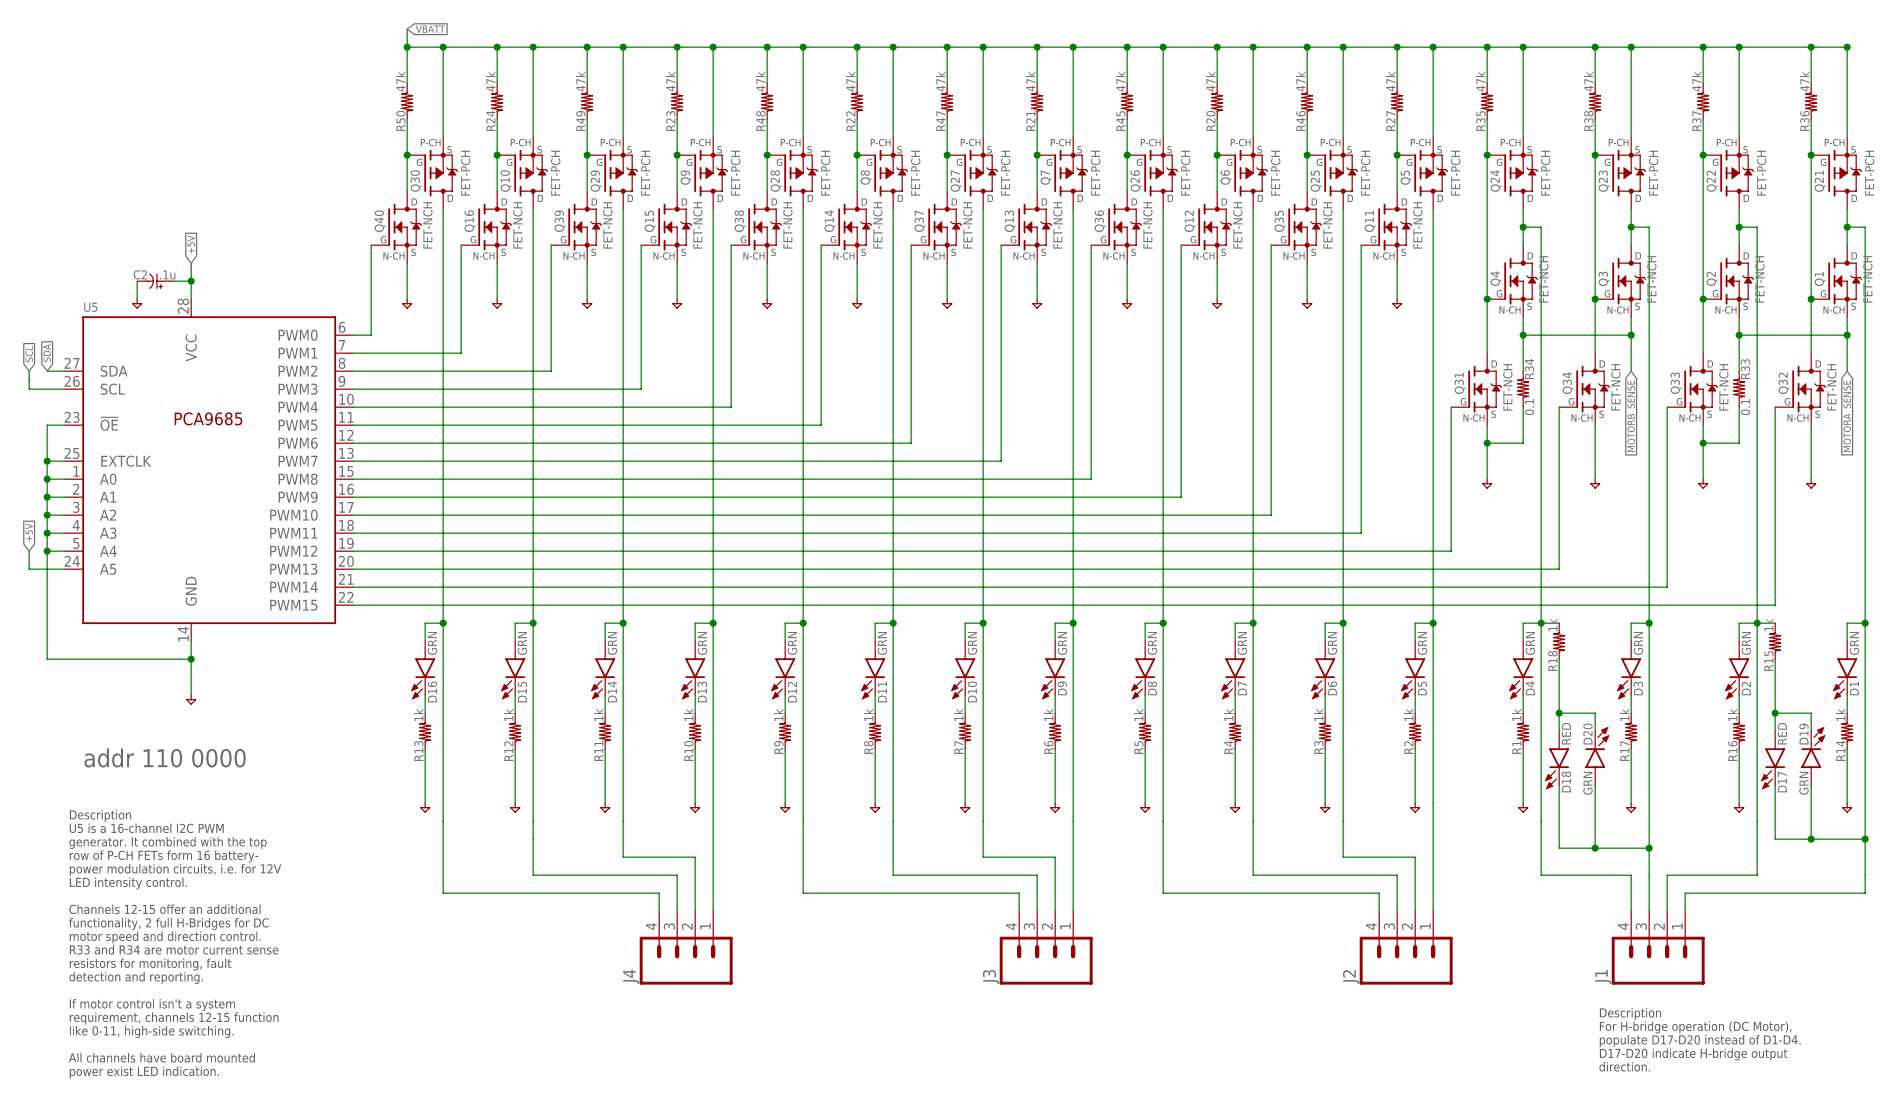
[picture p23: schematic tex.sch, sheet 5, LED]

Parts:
C2: .1u; C0603
D1, D2, D3, D4, D5, D6, D7, D8, D9, D10, D11, D12, D13, D14, D15, D16, D19, D20: GRN; LED0603
D17, D18: RED; LED0603
J1, J2, J3, J4: CONN-04-PLUGIN-SCREW; CONN-3.81MM-KF2EDG-4
Q1, Q2, Q3, Q4: FET-NCH; TO252
Q5, Q6, Q7, Q8, Q9, Q10, Q21, Q22, Q23, Q24, Q25, Q26, Q27, Q28, Q29, Q30: FET-PCH; TO252
Q11, Q12, Q13, Q14, Q15, Q16, Q31, Q32, Q33, Q34, Q35, Q36, Q37, Q38, Q39, Q40: FET-NCH; SOT23-3
R1, R2, R3, R4, R5, R6, R7, R8, R9, R10, R11, R12, R13, R14, R15, R16, R17, R18: 1k; R0603
R20, R21, R22, R23, R24, R27, R35, R36, R37, R38, R45, R46, R47, R48, R49, R50: 47k; R0603
R33, R34: 0.1; R1210
U5: PCA9685; TSSOP28

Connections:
+5V: C2.1, U5.24 (A5), U5.28 (VCC); also elsewhere on the board
GND: C2.2, Q11.2 (S), Q12.2 (S), Q13.2 (S), Q14.2 (S), Q15.2 (S), Q16.2 (S), Q31.2 (S), Q32.2 (S), Q33.2 (S), Q34.2 (S), Q35.2 (S), Q36.2 (S), Q37.2 (S), Q38.2 (S), Q39.2 (S), Q40.2 (S), R1.1, R2.1, R3.1, R4.1, R5.1, R6.1, R7.1, R8.1, R9.1, R10.1, R11.1, R12.1, R13.1, R14.1, R16.1, R17.1, R33.2, R34.2, U5.1 (A0), U5.2 (A1), U5.3 (A2), U5.4 (A3), U5.5 (A4), U5.14 (GND), U5.23 (!OE), U5.25 (EXTCLK); also elsewhere on the board
MOTORA_SENSE: Q1.2 (S), Q2.2 (S), R33.1; also elsewhere on the board
MOTORB_SENSE: Q3.2 (S), Q4.2 (S), R34.1; also elsewhere on the board
unnamed: Q40.1 (G), U5.6 (PWM0)
unnamed: Q6.1 (G), Q12.3 (D), R20.1
unnamed: Q26.1 (G), Q36.3 (D), R45.1
unnamed: Q7.1 (G), Q13.3 (D), R21.1
unnamed: Q27.1 (G), Q37.3 (D), R47.1
unnamed: Q8.1 (G), Q14.3 (D), R22.1
unnamed: Q28.1 (G), Q38.3 (D), R48.1
unnamed: Q9.1 (G), Q15.3 (D), R23.1
unnamed: Q29.1 (G), Q39.3 (D), R49.1
unnamed: Q10.1 (G), Q16.3 (D), R24.1
unnamed: Q30.1 (G), Q40.3 (D), R50.1
unnamed: Q16.1 (G), U5.7 (PWM1)
unnamed: Q39.1 (G), U5.8 (PWM2)
unnamed: Q15.1 (G), U5.9 (PWM3)
unnamed: Q38.1 (G), U5.10 (PWM4)
unnamed: Q14.1 (G), U5.11 (PWM5)
unnamed: Q37.1 (G), U5.12 (PWM6)
unnamed: Q13.1 (G), U5.13 (PWM7)
unnamed: Q36.1 (G), U5.15 (PWM8)
unnamed: Q12.1 (G), U5.16 (PWM9)
unnamed: D2.A, J1.2, Q2.3 (D), Q22.3 (D), R15.2
unnamed: Q2.1 (G), Q22.1 (G), Q33.3 (D), R37.1
unnamed: D1.A, D17.C, D19.A, J1.1, Q1.3 (D), Q21.3 (D)
unnamed: Q1.1 (G), Q21.1 (G), Q32.3 (D), R36.1
unnamed: Q32.1 (G), U5.22 (PWM15)
unnamed: Q33.1 (G), U5.21 (PWM14)
unnamed: D4.A, J1.4, Q4.3 (D), Q24.3 (D), R18.2
unnamed: Q4.1 (G), Q24.1 (G), Q31.3 (D), R35.1
unnamed: D16.A, J4.4, Q30.3 (D)
unnamed: D15.A, J4.3, Q10.3 (D)
unnamed: D14.A, J4.2, Q29.3 (D)
unnamed: D13.A, J4.1, Q9.3 (D)
unnamed: D12.A, J3.4, Q28.3 (D)
unnamed: D11.A, J3.3, Q8.3 (D)
unnamed: D10.A, J3.2, Q27.3 (D)
unnamed: D9.A, J3.1, Q7.3 (D)
unnamed: D8.A, J2.4, Q26.3 (D)
unnamed: D7.A, J2.3, Q6.3 (D)
unnamed: D13.C, R10.2
unnamed: D12.C, R9.2
unnamed: D1.C, R14.2
unnamed: D2.C, R16.2
unnamed: D3.C, R17.2
unnamed: D4.C, R1.2
unnamed: D14.C, R11.2
unnamed: D15.C, R12.2
unnamed: D16.C, R13.2
unnamed: D3.A, D18.C, D20.A, J1.3, Q3.3 (D), Q23.3 (D)
unnamed: Q3.1 (G), Q23.1 (G), Q34.3 (D), R38.1
unnamed: Q34.1 (G), U5.20 (PWM13)
unnamed: Q31.1 (G), U5.19 (PWM12)
unnamed: D18.A, D20.C, R18.1
unnamed: Q35.1 (G), U5.17 (PWM10)
unnamed: Q11.1 (G), U5.18 (PWM11)
unnamed: D17.A, D19.C, R15.1
unnamed: D6.A, J2.2, Q25.3 (D)
unnamed: D5.A, J2.1, Q5.3 (D)
unnamed: Q5.1 (G), Q11.3 (D), R27.1
unnamed: Q25.1 (G), Q35.3 (D), R46.1
unnamed: D5.C, R2.2
unnamed: D6.C, R3.2
unnamed: D7.C, R4.2
unnamed: D8.C, R5.2
unnamed: D9.C, R6.2
unnamed: D10.C, R7.2
unnamed: D11.C, R8.2
SCL: U5.26 (SCL); also elsewhere on the board
SDA: U5.27 (SDA); also elsewhere on the board
VBATT: Q5.2 (S), Q6.2 (S), Q7.2 (S), Q8.2 (S), Q9.2 (S), Q10.2 (S), Q21.2 (S), Q22.2 (S), Q23.2 (S), Q24.2 (S), Q25.2 (S), Q26.2 (S), Q27.2 (S), Q28.2 (S), Q29.2 (S), Q30.2 (S), R20.2, R21.2, R22.2, R23.2, R24.2, R27.2, R35.2, R36.2, R37.2, R38.2, R45.2, R46.2, R47.2, R48.2, R49.2, R50.2; also elsewhere on the board

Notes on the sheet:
addr 110 0000
Description U5 is a 16-channel I2C PWM generator. It combined with the top row of P-CH FETs form 16 battery- power modulation circuits, i.e. for 12V LED intensity control. Channels 12-15 offer an additional functionality, 2 full H-Bridges for DC motor speed and direction control. R33 and R34 are mo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
Description For H-bridge operation (DC Motor), populate D17-D20 instead of D1-D4. D17-D20 indicate H-bridge output direction.

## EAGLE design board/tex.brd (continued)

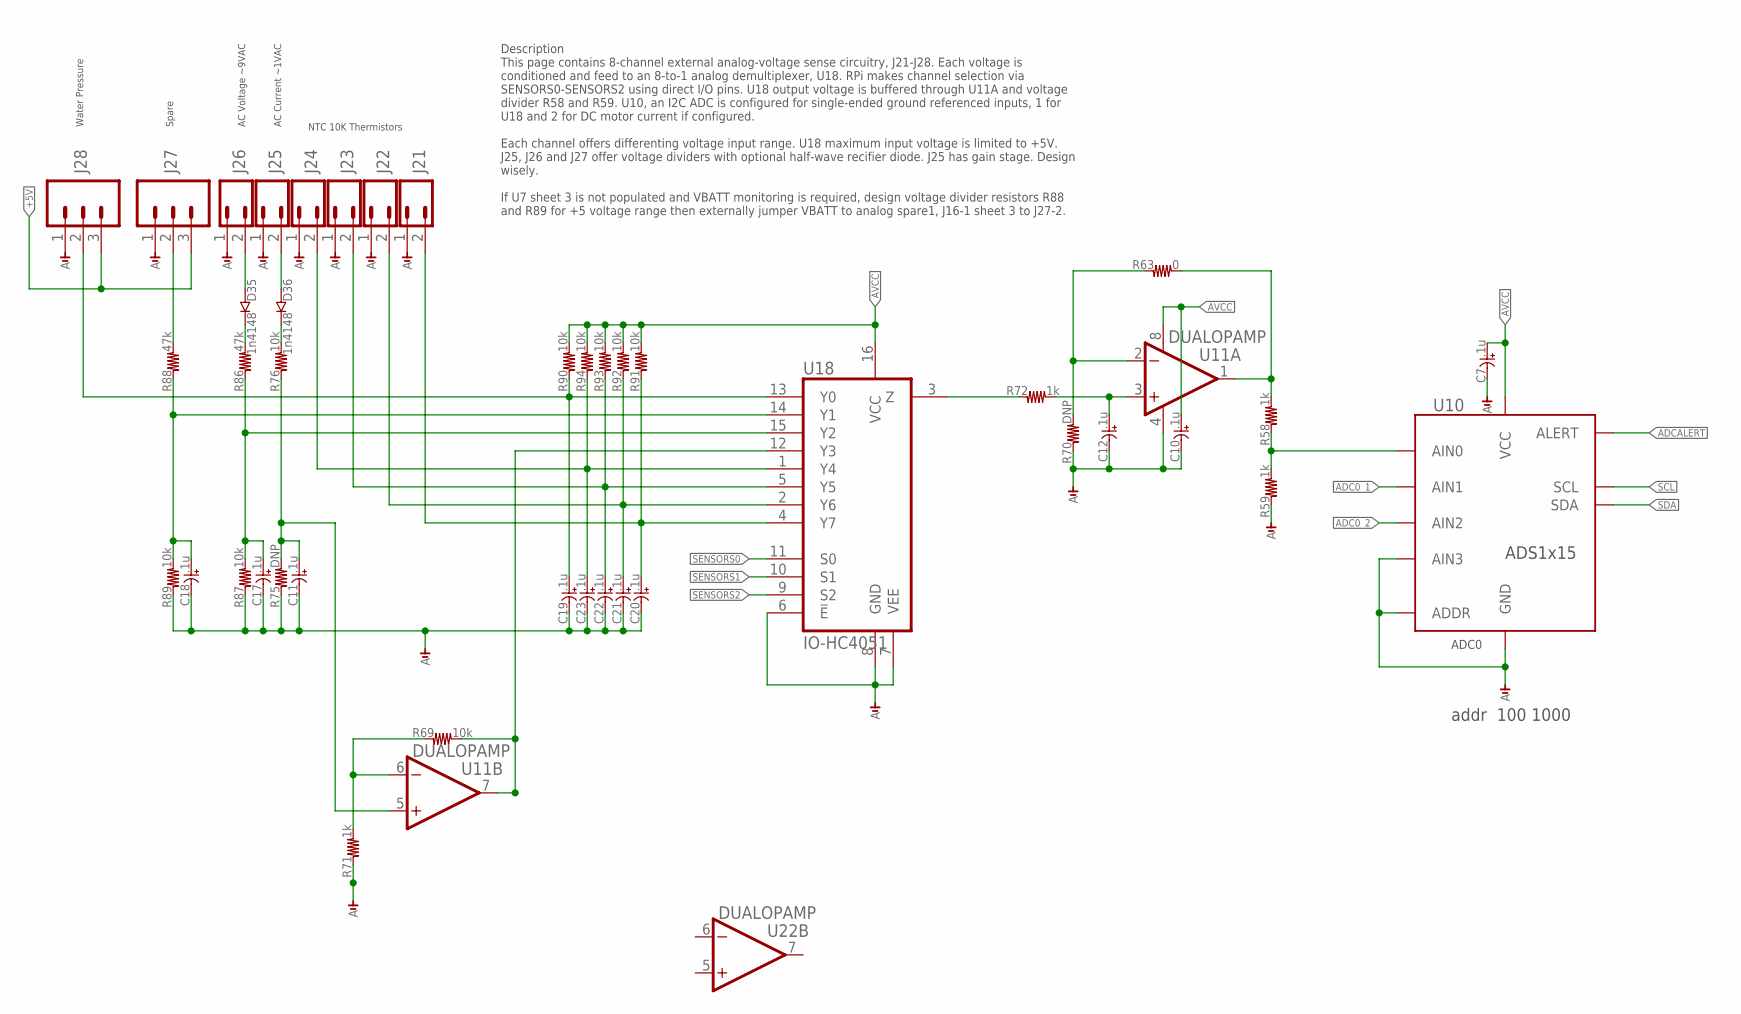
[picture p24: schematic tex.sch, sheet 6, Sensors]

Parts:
C7, C10, C11, C12, C17, C18, C19, C20, C21, C22, C23: .1u; C0603
D35, D36: 1n4148; SOD-523
J21, J22, J23, J24, J25, J26: CONN-02-PLUGIN-SCREW; CONN-3.81MM-KF2EDG-2
J27, J28: CONN-03-PLUGIN-SCREW; CONN-3.81MM-KF2EDG-3
R58, R59, R71, R72: 1k; R0603
R63: 0; R0603
R69, R76, R87, R89, R90, R91, R92, R93, R94: 10k; R0603
R70, R75: DNP; R0603
R86, R88: 47k; R0603
U10: ADS1x15; MSOP10_0.5
U11, U22: DUALOPAMP; SO08
U18: IO-HC4051; SO16

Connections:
+5V: J27.3, J28.3; also elsewhere on the board
ADC0_1: U10.5 (AIN1); also elsewhere on the board
ADC0_2: U10.6 (AIN2); also elsewhere on the board
ADCALERT: U10.2 (ALERT); also elsewhere on the board
AGND: C7.2, C10.2, C11.2, C12.2, C17.2, C18.2, C19.2, C20.2, C21.2, C22.2, C23.2, J21.1, J22.1, J23.1, J24.1, J25.1, J26.1, J27.1, J28.1, R59.1, R70.1, R71.1, R75.1, R87.1, R89.1, U10.1 (ADDR), U10.3 (GND), U10.7 (AIN3), U11.4 (V-), U18.6 (!E), U18.7 (VEE), U18.8 (GND); also elsewhere on the board
AVCC: C7.1, C10.1, R90.2, R91.2, R92.2, R93.2, R94.2, U10.8 (VCC), U11.8 (V+), U18.16 (VCC); also elsewhere on the board
unnamed: D35.C, R86.2
unnamed: D35.A, J26.2
unnamed: D36.C, R76.2
unnamed: D36.A, J25.2
unnamed: J27.2, R88.2
unnamed: R63.1, R70.2, U11.2 (-IN)
unnamed: R69.1, R71.2, U11.6 (-IN)
unnamed: C12.1, R72.2, U11.3 (+IN)
unnamed: C19.1, J28.2, R90.1, U18.13 (Y0)
unnamed: C18.1, R88.1, R89.2, U18.14 (Y1)
unnamed: C17.1, R86.1, R87.2, U18.15 (Y2)
unnamed: C11.1, R75.2, R76.1, U11.5 (+IN)
unnamed: C23.1, J24.2, R94.1, U18.1 (Y4)
unnamed: C22.1, J23.2, R93.1, U18.5 (Y5)
unnamed: C21.1, J22.2, R92.1, U18.2 (Y6)
unnamed: C20.1, J21.2, R91.1, U18.4 (Y7)
unnamed: R58.2, R63.2, U11.1 (OUT)
unnamed: R72.1, U18.3 (Z)
unnamed: R58.1, R59.2, U10.4 (AIN0)
unnamed: R69.2, U11.7 (OUT), U18.12 (Y3)
SCL: U10.10 (SCL); also elsewhere on the board
SDA: U10.9 (SDA); also elsewhere on the board
SENSORS0: U18.11 (S0); also elsewhere on the board
SENSORS1: U18.10 (S1); also elsewhere on the board
SENSORS2: U18.9 (S2); also elsewhere on the board
V+: U22.8 (V+)
V-: U22.4 (V-)

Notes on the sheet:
ADC0
NTC 10K Thermistors
Water Pressure
Spare
AC Voltage ~9VAC
AC Current ~1VAC
addr 100 1000
Description This page contains 8-channel external analog-voltage sense circuitry, J21-J28. Each voltage is conditioned and feed to an 8-to-1 analog demultiplexer, U18. RPi makes channel selection via SENSORS0-SENSORS2 using direct I/O pins. U18 output voltage is buffered through U11A and voltage di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

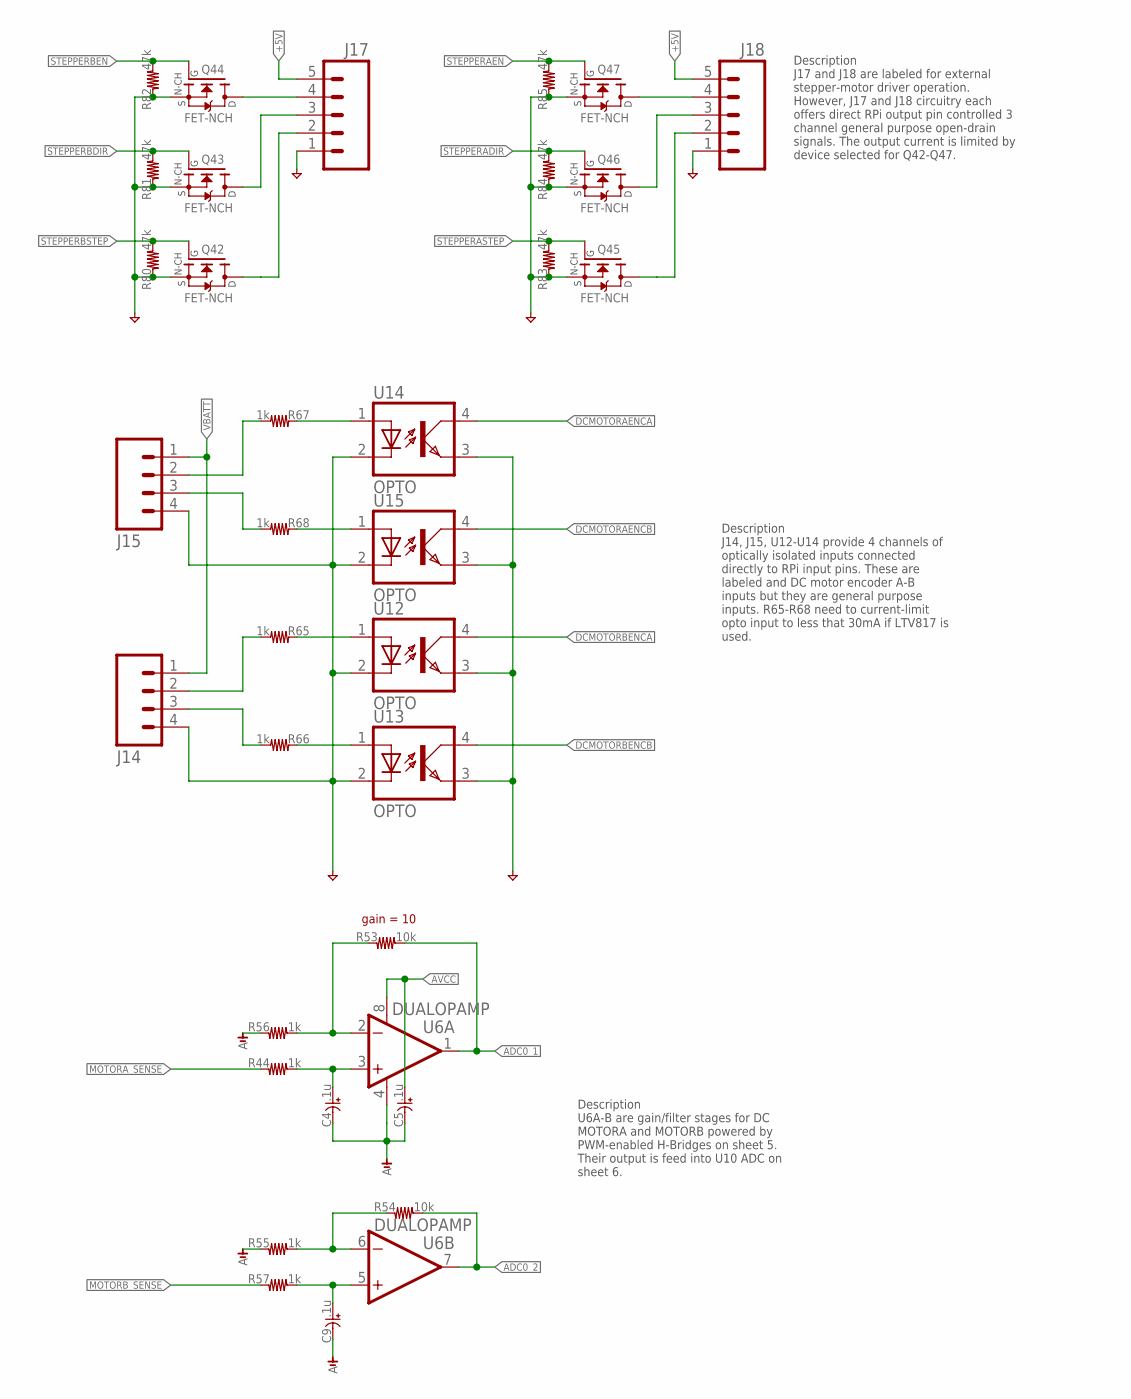
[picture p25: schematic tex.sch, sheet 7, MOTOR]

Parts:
C4, C5, C9: .1u; C0603
J14, J15: CONN-04-PLUGIN-SCREW; CONN-3.81MM-KF2EDG-4
J17, J18: CONN-05-PLUGIN-SCREW; CONN-3.81MM-KF2EDG-5
Q42, Q43, Q44, Q45, Q46, Q47: FET-NCH; SOT23-3
R44, R55, R56, R57, R65, R66, R67, R68: 1k; R0603
R53, R54: 10k; R0603
R80, R81, R82, R83, R84, R85: 47k; R0603
U6: DUALOPAMP; SO08
U12, U13, U14, U15: OPTO; LTV817

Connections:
+5V: J17.5, J18.5; also elsewhere on the board
ADC0_1: R53.2, U6.1 (OUT); also elsewhere on the board
ADC0_2: R54.2, U6.7 (OUT); also elsewhere on the board
AGND: C4.2, C5.2, C9.2, R55.1, R56.1, U6.4 (V-); also elsewhere on the board
AVCC: C5.1, U6.8 (V+); also elsewhere on the board
DCMOTORAENCA: U14.4; also elsewhere on the board
DCMOTORAENCB: U15.4; also elsewhere on the board
DCMOTORBENCA: U12.4; also elsewhere on the board
DCMOTORBENCB: U13.4; also elsewhere on the board
GND: J14.4, J15.4, J17.1, J18.1, Q42.2 (S), Q43.2 (S), Q44.2 (S), Q45.2 (S), Q46.2 (S), Q47.2 (S), R80.1, R81.1, R82.1, R83.1, R84.1, R85.1, U12.2, U12.3, U13.2, U13.3, U14.2, U14.3, U15.2, U15.3; also elsewhere on the board
MOTORA_SENSE: R44.1; also elsewhere on the board
MOTORB_SENSE: R57.1; also elsewhere on the board
unnamed: C4.1, R44.2, U6.3 (+IN)
unnamed: R54.1, R55.2, U6.6 (-IN)
unnamed: R53.1, R56.2, U6.2 (-IN)
unnamed: C9.1, R57.2, U6.5 (+IN)
unnamed: R67.1, U14.1
unnamed: J15.3, R68.2
unnamed: J15.2, R67.2
unnamed: J17.2, Q42.3 (D)
unnamed: J18.4, Q47.3 (D)
unnamed: J18.3, Q46.3 (D)
unnamed: J18.2, Q45.3 (D)
unnamed: R68.1, U15.1
unnamed: J14.2, R65.2
unnamed: J14.3, R66.2
unnamed: R65.1, U12.1
unnamed: R66.1, U13.1
STEPPER1DIROUT: J17.3, Q43.3 (D)
STEPPER1ENOUT: J17.4, Q44.3 (D)
STEPPERADIR: Q46.1 (G), R84.2; also elsewhere on the board
STEPPERAEN: Q47.1 (G), R85.2; also elsewhere on the board
STEPPERASTEP: Q45.1 (G), R83.2; also elsewhere on the board
STEPPERBDIR: Q43.1 (G), R81.2; also elsewhere on the board
STEPPERBEN: Q44.1 (G), R82.2; also elsewhere on the board
STEPPERBSTEP: Q42.1 (G), R80.2; also elsewhere on the board
VBATT: J14.1, J15.1; also elsewhere on the board

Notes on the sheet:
gain = 10
Description J17 and J18 are labeled for external stepper-motor driver operation. However, J17 and J18 circuitry each offers direct RPi output pin controlled 3 channel general purpose open-drain signals. The output current is limited by device selected for Q42-Q47.
Description J14, J15, U12-U14 provide 4 channels of optically isolated inputs connected directly to RPi input pins. These are labeled and DC motor encoder A-B inputs but they are general purpose inputs. R65-R68 need to current-limit opto input to less that 30mA if LTV817 is used.
Description U6A-B are gain/filter stages for DC MOTORA and MOTORB powered by PWM-enabled H-Bridges on sheet 5. Their output is feed into U10 ADC on sheet 6.

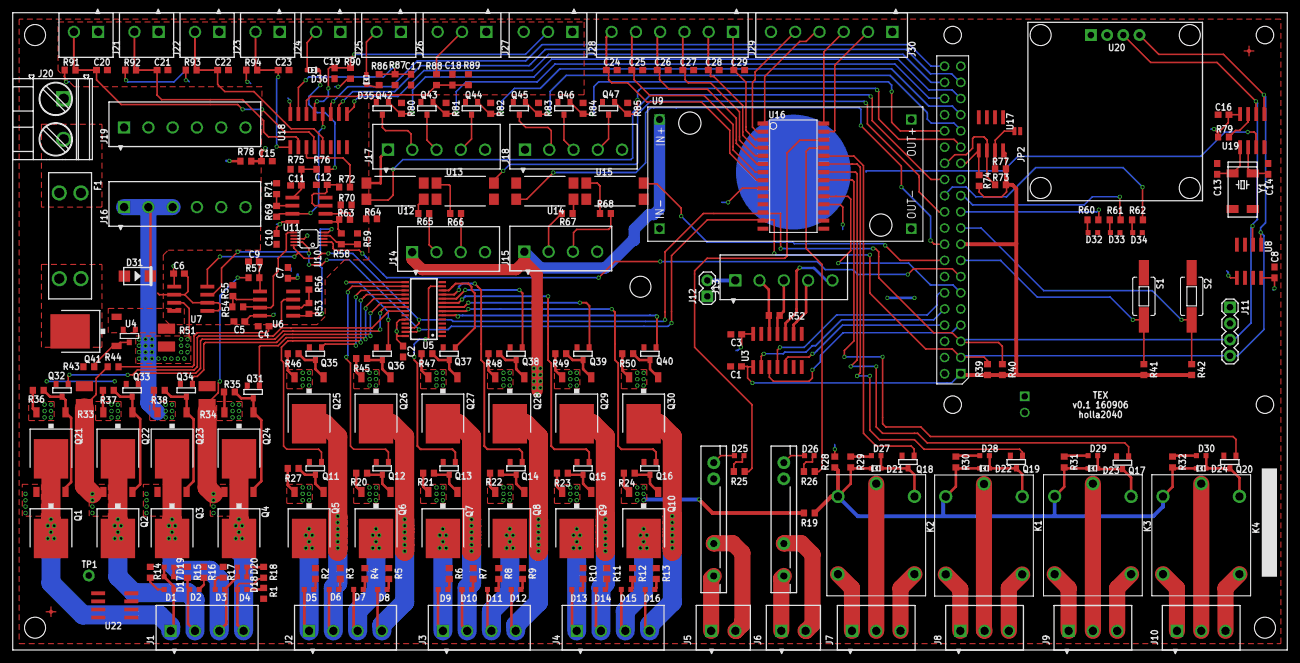
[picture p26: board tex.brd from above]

Board: 2 copper layers, 200.0 x 100.0 mm, 271 parts (1 on the bottom side), 204 nets.

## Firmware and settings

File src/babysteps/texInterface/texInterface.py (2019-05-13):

#!/usr/bin/env python3

import sys, os
(filePath, fileName) = os.path.split(__file__)
sys.path.insert(0,os.path.join(filePath, "lib"))

from temperatureSensor import TemperatureSensor
import RPi.GPIO as gpio # ToDo: Change this to Adafruit_GPIO
import Adafruit_PCA9685
from ina219 import INA219 # Only a Adafruit CircuitPython driver is available
from ina219 import DeviceRangeError

class TexInterface():

    class PWM_LIGHT_LEVEL:
        LOW = 0.0
        HIGH = 1.0

    # LED controller is a PWM, pulse width modulation, controller
    fPWM = 50 # Frequencey of led controller. Range 40-1000Hz
    ledLow = 0
    ledHigh = 4095 # PWM has 12 bits of resolution: 0 to 2^12-1 = 0 to 4095
    ledControllerAddress = 0x60
    tempSensorAddress = 0x4C
    ledPinRed = 11
    ledPinGreen = 9 
    ledPinBlue = 8
    shunt_ohms = 0.15   # for INA219 current sensor

    
    def __init__(self,debug=False):
        self.debug = debug

        self.tempSensor = None
        self.ledController = None
        self.currentPowerMonitor = None

        gpio.setmode(gpio.BCM)
        gpio.setup(TexInterface.ledPinRed, gpio.OUT)
        gpio.setup(TexInterface.ledPinGreen, gpio.OUT)
        gpio.setup(TexInterface.ledPinBlue, gpio.OUT)

    def cleanup(self,cleanUpGPIO=True):
        if cleanUpGPIO:
            gpio.cleanup()
        
    def helloWorld(self):
        print("Hello world")


    # Temperature Sensor
    def createTempSensor(self):
        if None == self.tempSensor:
            self.tempSensor = TemperatureSensor(address=TexInterface.tempSensorAddress)

    def getTempC(self):
        self.createTempSensor()
        return self.tempSensor.getTempC()
    
    def getTempF(self):
        self.createTempSensor()
        return self.tempSensor.getTempF()

    # Red, Grean and Blue LED
    def blueLightOn(self):
        gpio.output(TexInterface.ledPinBlue, gpio.HIGH)

    def blueLightOff(self):
        gpio.output(TexInterface.ledPinBlue, gpio.LOW)

    def redLightOn(self):
        gpio.output(TexInterface.ledPinRed, gpio.HIGH)

    def redLightOff(self):
        gpio.output(TexInterface.ledPinRed, gpio.LOW)

    def greenLightOn(self):
        gpio.output(TexInterface.ledPinGreen, gpio.HIGH)

    def greenLightOff(self):
        gpio.output(TexInterface.ledPinGreen, gpio.LOW)
    
    # LED Controller
    def createLedController(self):
        if None == self.ledController:
            self.ledController = Adafruit_PCA9685.PCA9685(address=TexInterface.ledControllerAddress)  # This takes additional arguments: address and i2c
            self.ledController.set_pwm_freq(TexInterface.fPWM) #Set the PWM frequency in hertz
            
    def ledSetLevel(self, level, ledNumber):
        '''
        Set light level to 'level' of led number 'ledNumber'
        where level is a float between TexInterface.PWM_LIGHT_LEVEL.LOW and TexInterface.PWM_LIGHT_LEVEL.HIGH
        and ledNumber is an integer representing led 0 to 15
        '''
        if not (isinstance(level, float) or isinstance(level, int)):
            msg = "Argument level is of the wrong type sent to "+\
                  "TexInterface.ledSetLevel(level=%s,ledNumber=%s). " % (level, ledNumber)+\
                  "Expection float or int but got %s" % type(level)
            raise TypeError(msg)
        if not isinstance(ledNumber, int):
            msg = "Argument ledNumber is of the wrong type sent to "+\
                  "TexInterface.ledSetLevel(level=%s,ledNumber=%s). " % (level, ledNumber)+\
                  "Expection float or int but got %s" % type(ledNumber)
            raise TypeError(msg)
        if (level < TexInterface.PWM_LIGHT_LEVEL.LOW or level > TexInterface.PWM_LIGHT_LEVEL.HIGH):
            msg = "Bad value of level sent to "+\
                  "TexInterface.ledSetLevel(level=%s,ledNumber=%s). " % (level, ledNumber)+\
                  "Expeced float between " +\
                  "TexInterface.PWM_LIGHT_LEVEL.LOW(=%s) " % TexInterface.PWM_LIGHT_LEVEL.LOW +\
                  "and TexInterface.PWM_LIGHT_LEVEL.HIGH(=%s)" % TexInterface.PWM_LIGHT_LEVEL.LOW
            raise ValueError(msg)
        if (ledNumber < 0 or ledNumber > 15):
            msg = "Bad value of ledNumber sent to "+\
                  "TexInterface.ledSetLevel(level=%s,ledNumber=%s). " % (level, ledNumber)+\
                  "Expeced integer between 0 and 15"
            raise ValueError(msg)
        self.createLedController()
        self.ledController.set_pwm(ledNumber,0,int(level*TexInterface.ledHigh))

    def ledOff(self,ledNumber):
        self.ledSetLevel(TexInterface.PWM_LIGHT_LEVEL.LOW,ledNumber)

    def ledOn(self,ledNumber):
        self.ledSetLevel(TexInterface.PWM_LIGHT_LEVEL.HIGH,ledNumber)

    def ledAllOff(self):
        for ledNumber in range (16):
            self.ledOff(ledNumber)
            
    def ledAllOn(self):
        for ledNumber in range (16):
            self.ledOn(ledNumber)
            
    def ledSetLevelAll(self,level):
        for ledNumber in range (16):
            self.ledSetLevel(level,ledNumber)
    
    # Current/Power Monitor
    def createCurrentPowerMonitor(self):
        if None == self.currentPowerMonitor:
            self.currentPowerMonitor = INA219(TexInterface.shunt_ohms)
            self.currentPowerMonitor.configure()

    def getSupplyVoltage_V(self):
        """ Returns the bus supply voltage in volts. This is the sum of
        the bus voltage and shunt voltage. A DeviceRangeError
        exception is thrown if current overflow occurs."""
        self.createCurrentPowerMonitor()
        return self.currentPowerMonitor.supply_voltage()

    def getVoltageBus_V(self):
        """ Returns the bus voltage in volts. """
        self.createCurrentPowerMonitor()
        return self.currentPowerMonitor.voltage()

    def getVoltageShunt_mV(self):
        """ Returns the shunt voltage in millivolts.
        A DeviceRangeError exception is thrown if current overflow occurs."""
        self.createCurrentPowerMonitor()
        return self.currentPowerMonitor.shunt_voltage()

    def getCurrent_mA(self):
        """ Returns the bus current in milliamps. A DeviceRangeError
        exception is thrown if current overflow occurs."""
        self.createCurrentPowerMonitor()
        return self.currentPowerMonitor.current()

    def getPower_mW(self):
        """ Returns the bus power consumption in milliwatts.
        A DeviceRangeError exception is thrown if current overflow occurs."""
        self.createCurrentPowerMonitor()
        return self.currentPowerMonitor.power()

    def currentPowerMonitorSleep(self):
        """ Put the INA219 into power down mode. """
        self.createCurrentPowerMonitor()
        return self.currentPowerMonitor.sleep()

    def currentPowerMonitorWake(self):
        """ Wake the INA219 from power down mode """
        self.createCurrentPowerMonitor()
        return self.currentPowerMonitor.wake()

    def getCurrentPowerMonitorCurrentOverflow(self):
        """ Returns true if the sensor has detect current overflow. In
        this case the current and power values are invalid."""
        self.createCurrentPowerMonitor()
        return self.currentPowerMonitor.current_overflow()
    
    def currentPowerMonitorReset(self):
        """ Reset the INA219 to its default configuration. """
        self.createCurrentPowerMonitor()
        return self.currentPowerMonitor.reset()

if __name__ == "__main__":
    tex = TexInterface()
    tex.helloWorld()
    

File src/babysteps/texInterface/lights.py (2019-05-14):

#!/usr/bin/env python3

import sys, os, math, time
(filePath, fileName) = os.path.split(__file__)
sys.path.insert(0,os.path.join(filePath, "lib"))

from texInterface import TexInterface

class Light():

    ledNumbersUsed = { 0:False, 1:False, 2:False, 3:False,
                       4:False, 5:False, 6:False, 7:False,
                       8:False, 9:False,10:False,11:False,
                      12:False,13:False,14:False,15:False }

    class MODE():
        LIGHT_MODE_NOTSET = -1
        LIGHT_OFF = 0
        LIGHT_ON  = 1
        LIGHT_FLASHING = 2

    class LEVEL():
        HIGH  = TexInterface.PWM_LIGHT_LEVEL.HIGH
        LOW   = TexInterface.PWM_LIGHT_LEVEL.LOW
        
    def __init__(self,debug=False):
        #print ("In Light.__init__(debug)")
        self.debug = debug

        self.texInterface = None
        self.ledNumber    = None
        self.onLightLevel = None
        self.lightMode    = None
        self.lightLevel   = None

    def setup(self, texInterface, ledNumber, onLightLevel):
        self.texInterface = texInterface
        self.ledNumber    = ledNumber
        self.onLightLevel = onLightLevel
        self.off()

        assert Light.ledNumbersUsed[self.ledNumber] == False,\
            "A Light object is already using ledNumber %s" % self.ledNumber
        Light.ledNumbersUsed[self.ledNumber] = True

    def cleanup(self):
        self.off()
        Light.ledNumbersUsed[self.ledNumber] = False

    def setLightBrightness(self, lightLevel):
        '''
        Set the actual LED to the given lightLevel
        '''
        self.lightLevel = lightLevel # Used so can query for debugging
        self.texInterface.ledSetLevel(lightLevel, self.ledNumber)

    def update(self):
        '''
        A no-op, because for a simple Light, sine there is no time variation,
        actual light brightness are set in on and off
        '''
        pass
    
    def off(self):
        self.lightMode  = Light.MODE.LIGHT_OFF
        self.setLightBrightness(Light.LEVEL.LOW)

    def on(self):
        self.lightMode  = Light.MODE.LIGHT_ON
        self.setLightBrightness(self.onLightLevel)

    def toggle(self):
        if (self.lightMode == Light.MODE.LIGHT_MODE_NOTSET or
            self.lightMode == Light.MODE.LIGHT_FLASHING):
            pass
        elif self.lightMode == Light.MODE.LIGHT_OFF:
            self.on();
        elif self.lightMode == Light.MODE.LIGHT_ON:
            self.off();

    def setOnLightLevel(self, onLightLevel):
        self.onLightLevel = onLightLevel;
        if (self.lightMode == Light.MODE.LIGHT_ON):
            self.on();

    def incrementOnLightLevel(self, onLightLevelIncrement):
        onLightLevelValue = self.onLightLevel + onLightLevelIncrement;
        if (onLightLevelValue > Light.MODE.LIGHT_ON):
            onLightLevelValue = Light.MODE.LIGHT_ON
        elif (onLightLevelValue < Light.MODE.LIGHT_OFF):
            onLightLevelValue = Light.MODE.LIGHT_OFF;
        self.setOnLightLevel(onLightLevelValue);
  
    def getLightMode(self):
        return self.lightMode

class DecayLight(Light):
    """
    A light that is on, then switches off, but filament "cools" when light
    is switched off.
    For each interval, specify length of time 'onLength' light is on at
    'maxLightLevel'.  Then, for each interval, specify 'decayLength' how long
    light will spend in decay mode, which is either moving to off or off.
    Length of time moving to off (i.e. decaying) is governed by 'tau' and
    Newton's law of cooling, as desribed below.
  
    In this class the light level decays at a rate given by Newton's
    law of cooling, which is
   
    T = T_env + dT*exp(-t/tau)
    where:
      t = time
      tau = time constant
      T = Temperature at time t
      T_env = Temperature of the surrounding environment
      dT = Initial temperature difference in bodies (T_0 - T_env)
      T_0 = Temperature at time 0.
   
      tau = ro*V*c_p/h*A_s
      ro = density
      V = volume
      c_p = heat capacity
      A_s = surface area
      h = heat transfer coefficient
  
    Note:
    At t=0, T = T_0 = T_env + dT
    At t=tau,   T will have decreased by 63.2% to .368*dT
    At t=2*tau, T will have decreased by 86.5% to .135*dT  
   
    For us T_env = 0 and dT = maxLightLevel so
    light_level = maxLightLevel*exp(-time/(tau))
    where tau is given in seconds
    """

    def __init__(self,debug=False):
        #print ("In DecayLight.__init__(debug)")
        super().__init__(debug)
        self.decayStartTime  = 0 # Keep track of when decay started.
        self.changeTime      = 0 # Keep track of when its time to change modes
        self.decaying        = False # Bool if in on or decay mode
        self.intervalIndex   = 0 # Keep track which lighting inverval we are on
        self.numIntervals    = None # Length of arrays

        self.onLengthArray   = None # Arrays are documented in setup doc string
        self.decayLengthArray= None 
        self.maxLightLevelArray = None 
        self.tauArray        = None 

    def setup(self,texInterface, ledNumber, onLightLevel,
              onLengthArray, decayLengthArray,
              maxLightLevelArray, tauArray):
        '''
        texInterface       = The TexInterface object we are using for this LED
        ledNumber          = The LED we are talking to, 0-15
        onLightLevel       = Light level LED is set to when user calls on()
        onLengthArray      = Time to stay on before switching to 
                             decay mode, for each interval
        decayLengthArray   = Time to stay in decay mode, before 
                             starting next interval, for each interval
        maxLightLevelArray = Light level when on, for each interval
        tauArray           = Time constants in secs. See discussion above
        '''
        super().setup(texInterface, ledNumber, onLightLevel)
        assert (len(onLengthArray) == len(decayLengthArray) and
                len(onLengthArray) == len(maxLightLevelArray) and
                len(onLengthArray) == len(tauArray)),\
               "Expecting all array lenghts to be the same. "+\
               "len(onLengthArray) = %s, " % len(onLengthArray) +\
               "len(decayLengthArray) = %s, " % len(decayLengthArray) +\
               "len(maxLightLevelArray) = %s, " % len(maxLightLevelArray) +\
               "len(tauArray) = %s, " % len(tauArray)
        self.numIntervals = len(onLengthArray)
        # Overide call to off() made in Light::setup since we want this light
        # to be in flashing mode right away
        self.setLightBrightness(Light.LEVEL.LOW) # Set the initial light level
        self.lightMode = Light.MODE.LIGHT_FLASHING

        self.onLengthArray      = onLengthArray
        self.decayLengthArray   = decayLengthArray
        self.maxLightLevelArray = maxLightLevelArray
        self.tauArray           = tauArray
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

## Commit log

2016-01-11 initial add for most
    [use cases.ods]
2016-01-11 added turbine tab
    [use cases.ods]
2016-03-02 added notes on pwm control
2016-03-04 added parts to pwm output sheet
    [tex.brd, tex.sch, use cases.ods]
2016-08-23 continuing work on sch
    [tex.brd, tex.sch, use cases.ods]
2016-08-27 mostly layout changes
    [tex.brd, tex.sch, use cases.ods]
2016-09-06 parts placed
    [tex.brd, tex.sch]
2016-09-06 started routing changed rtc to MCP to have vbat
    [tex.brd, tex.sch]
2016-09-06 routing complete
    [tex.brd, tex.sch]
2016-09-07 ready to place names
    [tex.brd, tex.sch, use cases.ods]
2016-09-07 board file submission
    [tex.brd, tex.sch]
2016-09-07 found silk issues, tex-v0.1-gerber.zip submitted for production
    [tex.brd]
2016-09-27 set R and C values
    [tex.brd, tex.sch]
2016-11-28 changed connectors to match new lib naming
    [tex.brd, tex.sch]
2016-11-28 swapped relays for new part in holla lib
    [tex.brd, tex.sch]
2018-11-12 added descriptions to all circuit elements, generated update schematic
    [tex.brd, tex.sch]
2019-04-06 added part number
    [tex.brd, tex.sch]
2019-04-06 getting ready for first board run
    [tex.brd, tex.sch]
2019-04-12 initial add for blink
    [tex.brd, tex.sch]
2019-04-19 added a couple comments
2019-04-19 fixed SSR relay logic
2019-04-20 added todo items
    [tex.brd, tex.sch]
2019-04-20 added more notes
    [tex.sch]
2019-04-20 more notes
    [tex.brd, tex.sch]
2019-04-21 "led2.py: inital commit of file"
2019-05-02 "led2_adafruit.py: Initial commit"
2019-05-02 "led2_adafruit.py: Got it to work"
2019-05-03 "temperatureSensor.py: Added get for C and F and better printing"
2019-05-06 "led2_adafruit.py: Removed unneeded smbus import"
2019-05-06 "texInterface.py, testTexInterface.py: Added led controller"
2019-05-07 "testTexInterface.py: Putting RGB LED tests in order"
2019-05-07 "testTexInterface.py, texInterface.py: Added current/power monitor functionality and tests"
2019-05-13 "lights.py: Added DecayLight and various fixes"
    [lights.py]
2019-05-13 "texInterface.py: LIGHT_LEVEL -> PWM_LIGHT_LEVEL"
